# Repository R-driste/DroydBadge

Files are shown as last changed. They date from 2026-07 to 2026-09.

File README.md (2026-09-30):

# 🎫 Dristi Badge
WORK IN PROGRESS, HAS BEEN ORDERED, TROUBLESHOOTING PCB.

> A PCB hackathon badge featuring a camera, display, NFC, and thermal printer integration. Built on ESP32-S3, designed from scratch for the Outpost/Opensauce competition.

> Thank you to EasyEDA Spark for helping inspire my project, fund my PCB prototyping and supporting this endeavor. I strongly recommend it to other people looking to build new hardware.

**Key Intended Features:**
- Camera with live viewfinder
- Game mode with sprite support
- E-ink display
- NFC capability
- Thermal printer sticker output
- Rechargeable LiPo battery system
- SD card storage

---
## Board Images

<div align="center">
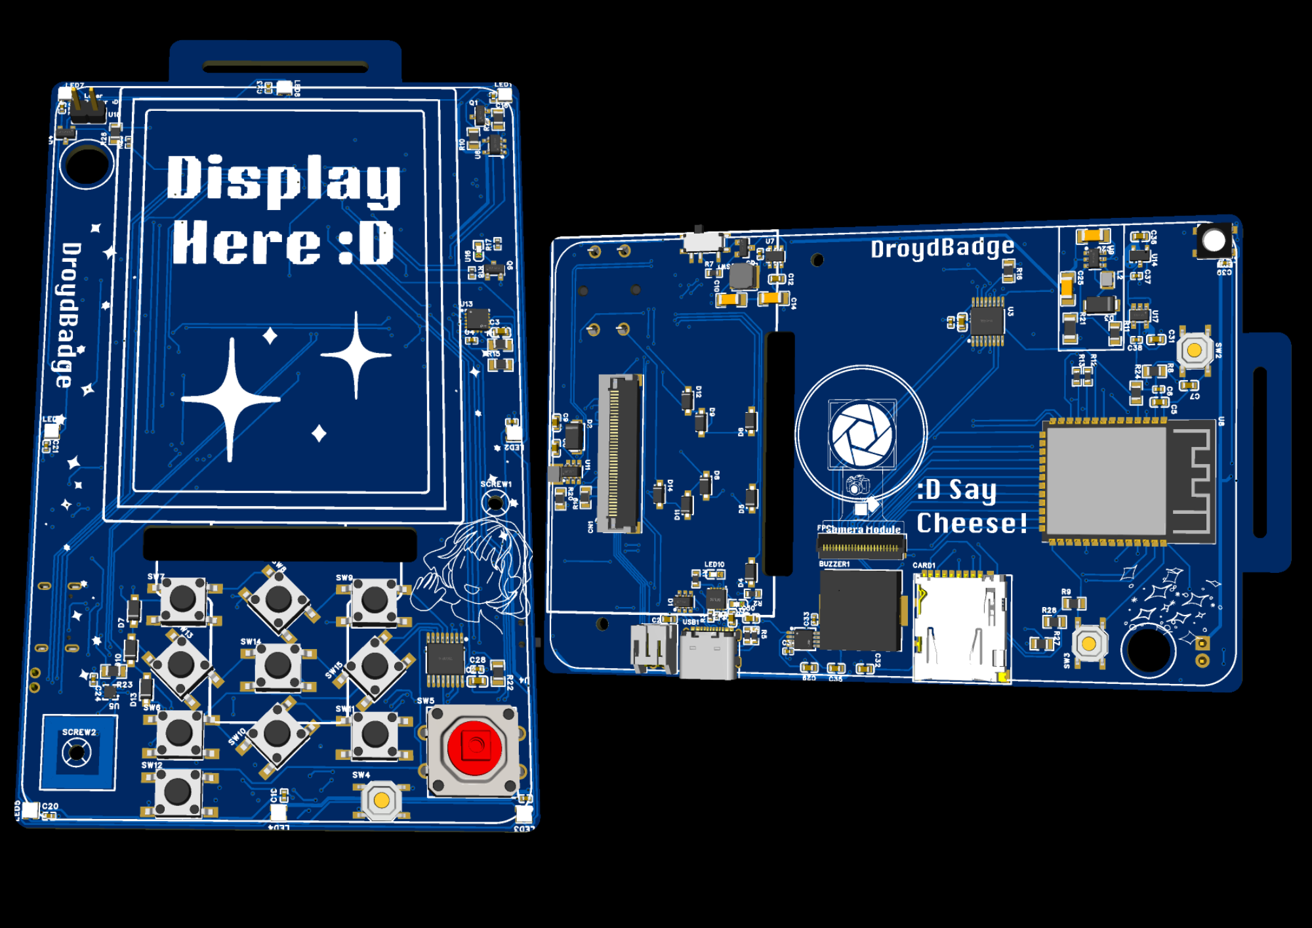
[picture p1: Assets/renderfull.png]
DroydBadge - Front View
  
</div>

<div align="center">
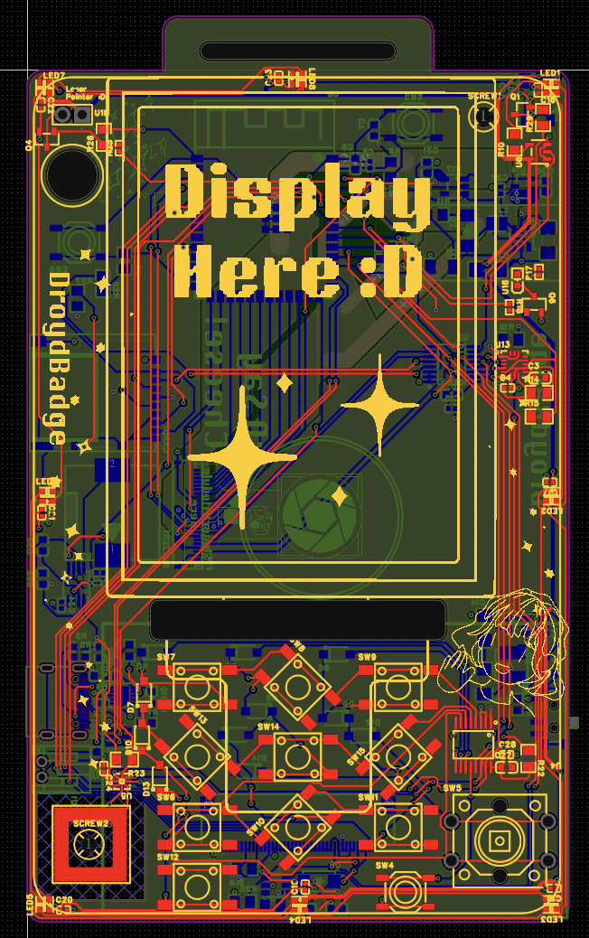
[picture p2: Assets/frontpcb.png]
PCB Layout - Top View
  
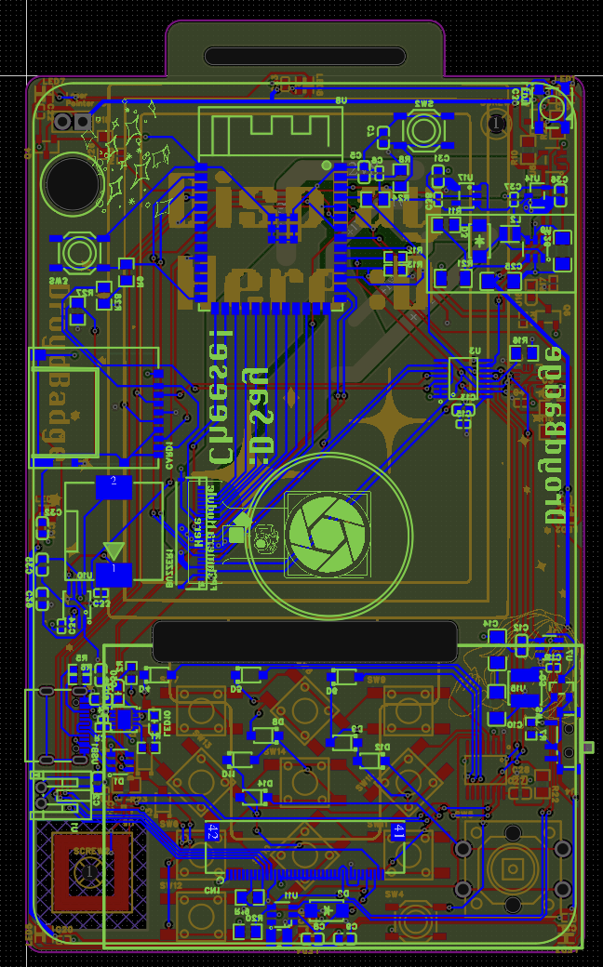
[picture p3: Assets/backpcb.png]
PCB Layout - Detailed View
  
</div>

<div align="center">
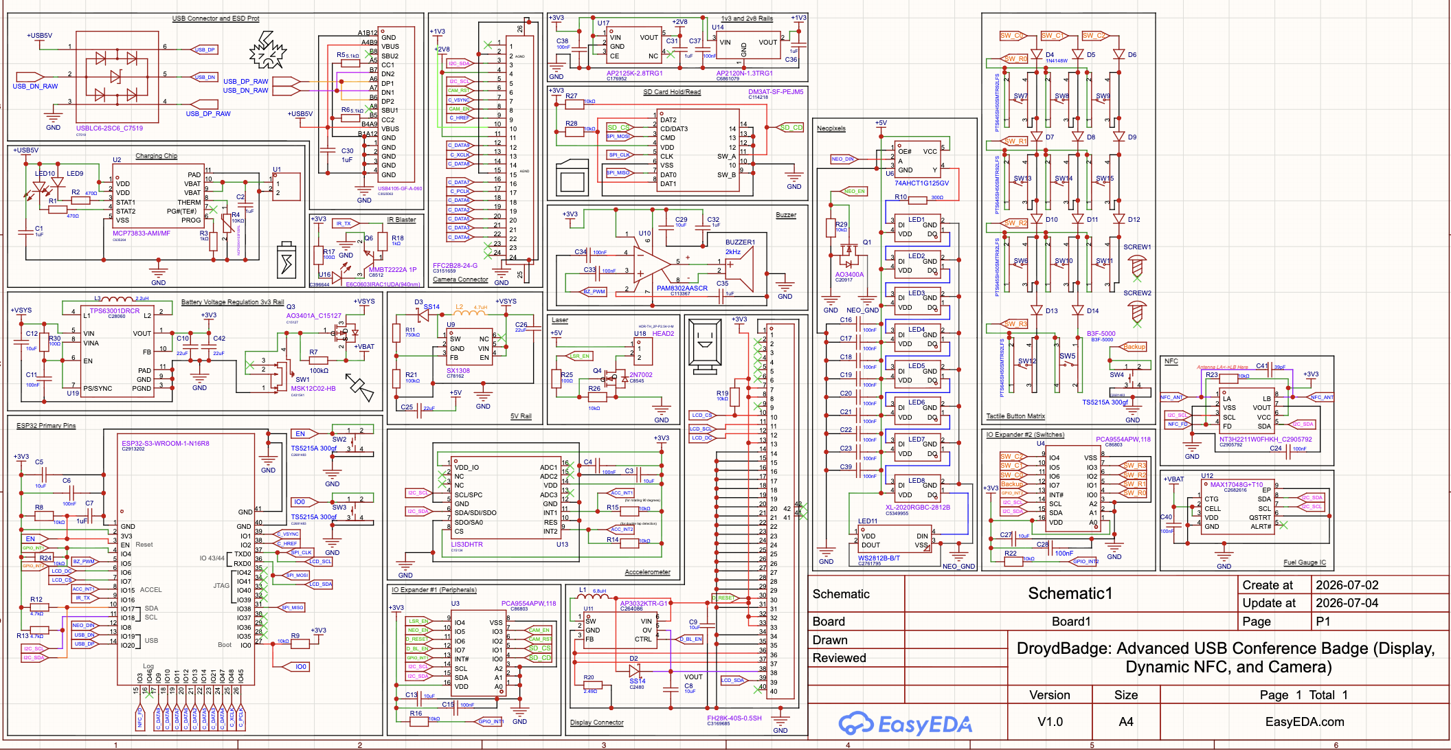
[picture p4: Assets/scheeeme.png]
Power System Schematic
  
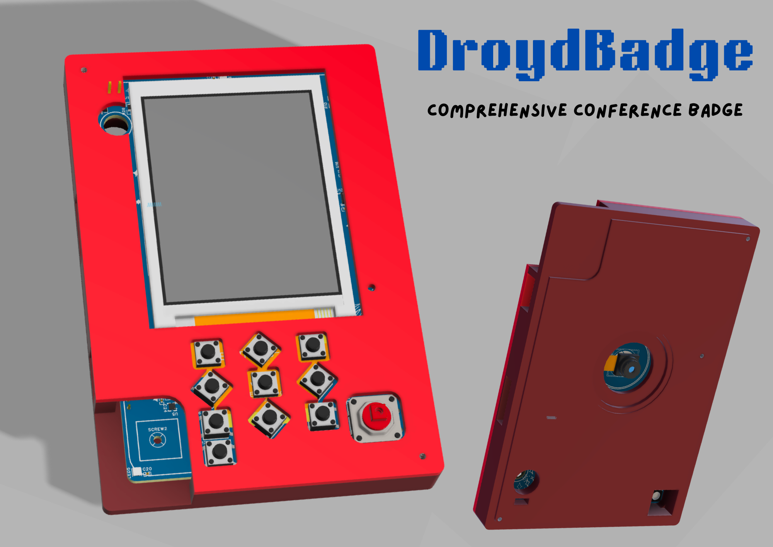
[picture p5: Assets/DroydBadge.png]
CAD
  
</div>

---

## 📁 Project Structure

- **CAD/** — 3D case design files
- **Gerber_PCB/** — PCB manufacturing files (Gerber format)
- **PCB/** — KiCad project files
- **Assets/** — Documentation and reference materials

## CAD CREDITS

Display Model
https://grabcad.com/library/serial-spi-2-8-tft-lcd-module-display-320x240-optional-touch-screen-1

Camera Model
https://grabcad.com/library/ov2640-2

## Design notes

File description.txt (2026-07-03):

3.1 ESP32 Primary Pins
U1 (ESP32-S3-WROOM-1-N16R8), the central MCU. Fans out I2C (I2C_SDA/SCL) to the accelerometer, NFC tag, and both IO expanders, SPI (SPI_MOSI/MISO/CLK) to the display and SD card, the dedicated camera DVP bus (C_DATA0-9, C_VSYNC, C_HREF, C_PCLK, C_XCLK), UART (RXD0/TXD0), and a JTAG header for debug. SW2 and SW3 (TS5215A) sit on EN and IO0 respectively, giving hardware reset and boot mode buttons.
3.2 USB Connector and ESD Protection
USB4105-GF-A-060 USB-C receptacle providing USB_DP/DN and VBUS. USBLC6-2SC6 clamps the raw D+/D- lines (USB_DP_RAW/USB_DN_RAW) before they reach the ESP32's native USB pins, protecting the exposed connector against ESD.
3.3 Battery Voltage Regulation
Q3 (AO3401A, P-channel MOSFET) load switches VBAT onto the +VSYS rail, letting the battery be gated off downstream when not needed.
3.4 Charging Chip
U2 (MCP73833-AMI/MF) linear LiPo charger. R4 is an NTC thermistor on the THERM pin for temperature qualified charging. STAT1/STAT2 drive LED9/LED10 through R3 (1k) as charge status indicators.
3.5 5V Rail
U9 (SX1308) boost converter steps VSYS up to +5V, using L2 (4.7uH), D2/D3 (SS14 Schottky) rectifiers, R10/R11/R21 feedback divider, and C25/C26 (22uF) output filtering.
3.6 3V3 Rail
U7 (AP63203WU-7) buck converter drops VSYS/5V to +3V3, using L1 (6.8uH) and C10/C14 (22uF) filtering. Powers the ESP32 and most digital peripherals.
3.7 NFC 1V3 and 2V8 Rails
Two linear LDOs isolate the NFC analog front end from the digital 3V3 rail. U14 (AP2120N-1.3) outputs +1V3, U17 (AP2125K-2.8) outputs +2V8, both sourced from +3V3. These feed the NT3H2211W0FHKH NFC IC directly, with LA/LB antenna pads broken out to a 2-pin header (HEAD2) for the loop antenna.
3.8 IO Expander #1 (Peripherals)
PCA9554APW on the I2C bus, adding 8 GPIOs for peripheral enable and reset lines that don't need to consume native ESP32 pins.
3.9 IO Expander #2 (Switches)
Second PCA9554APW reading the SW_R0-3/SW_C0-2 button matrix lines over the same I2C bus, offloading button scanning from the ESP32.
3.10 Tactile Button Matrix
9x PTS645SH50SMTR92LFS (SW7-SW15) in a 3x3 row and column grid. Diodes D6-D14 prevent ghosting on simultaneous key presses. R8/R9/R14-16/R19/R22-29 (10k) hold rows and columns at defined idle levels.
3.11 Backup Button
SW1 (MSK12C02-HB), pulled up via R7 (100k), on a dedicated Backup net, separate hardware input independent of the main matrix.
3.12 Accelerometer
U13 (LIS3DHTR) on I2C, with INT1/INT2 routed to GPIO_INT1/GPIO_INT2 for tap detection and orientation sensing. This is what detects the 90 degree rotation that triggers camera mode.
3.13 Camera Connector
FFC2B28-24-G (24-pin FPC) carries the OV2640's DVP bus (C_DATA0-9, VSYNC, HREF, PCLK, XCLK), I2C/SCCB config, CAM_EN power gate, and CAM_RST.
3.14 Display Connector
FH28K-40S-0.5SH (40-pin FPC) carries SPI (LCD_SCL/LCD_SDA), LCD_DC, LCD_CS, D_RESET, and D_BL_EN to the ILI9341V TFT. U15 (AP3032KTR-G1) is the backlight boost converter.
3.15 Neopixels
8x XL-2020RGBC-2812B (LED1-8) plus 1x WS2812B-B/T (LED11), chained on NEO_DIN and buffered through U6 (74AHCT1G125GV, 3.3V to 5V) to meet WS2812 signal timing. Q1 (AO3400A) gates power via NEO_EN.
3.16 Buzzer
Piezo (BUZZER1, 2kHz) driven differentially by U10 (PAM8302AASCR) class-D amp, fed by BZ_PWM.
3.17 IR Blaster
U16 (940nm IR LED) driven by Q6 (MMBT2222A) switched via IR_TX through R18 (1k) base resistor, with R25/R17 (100R) current limiting.
3.18 Laser
R20 (2.49R) sets current limit on the LSR_EN controlled laser driver path.
3.19 SD Card Hold/Read
DM3AT-SF-PEJM5 microSD holder providing DAT0-3, CMD, CLK, VDD/VSS, plus SD_CD (card detect) and SD_CS for SPI access.

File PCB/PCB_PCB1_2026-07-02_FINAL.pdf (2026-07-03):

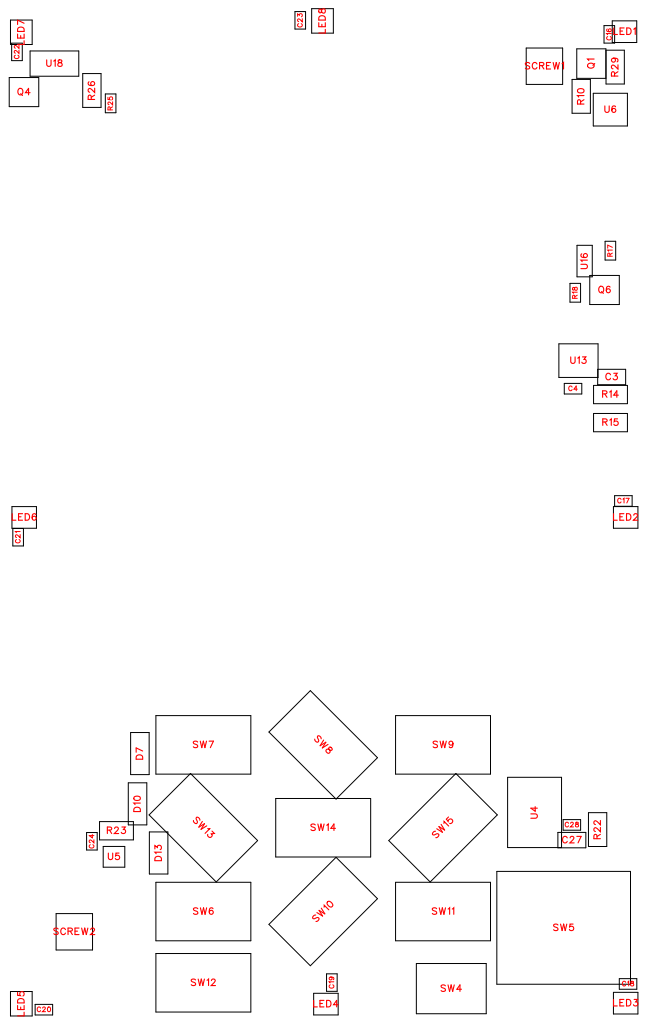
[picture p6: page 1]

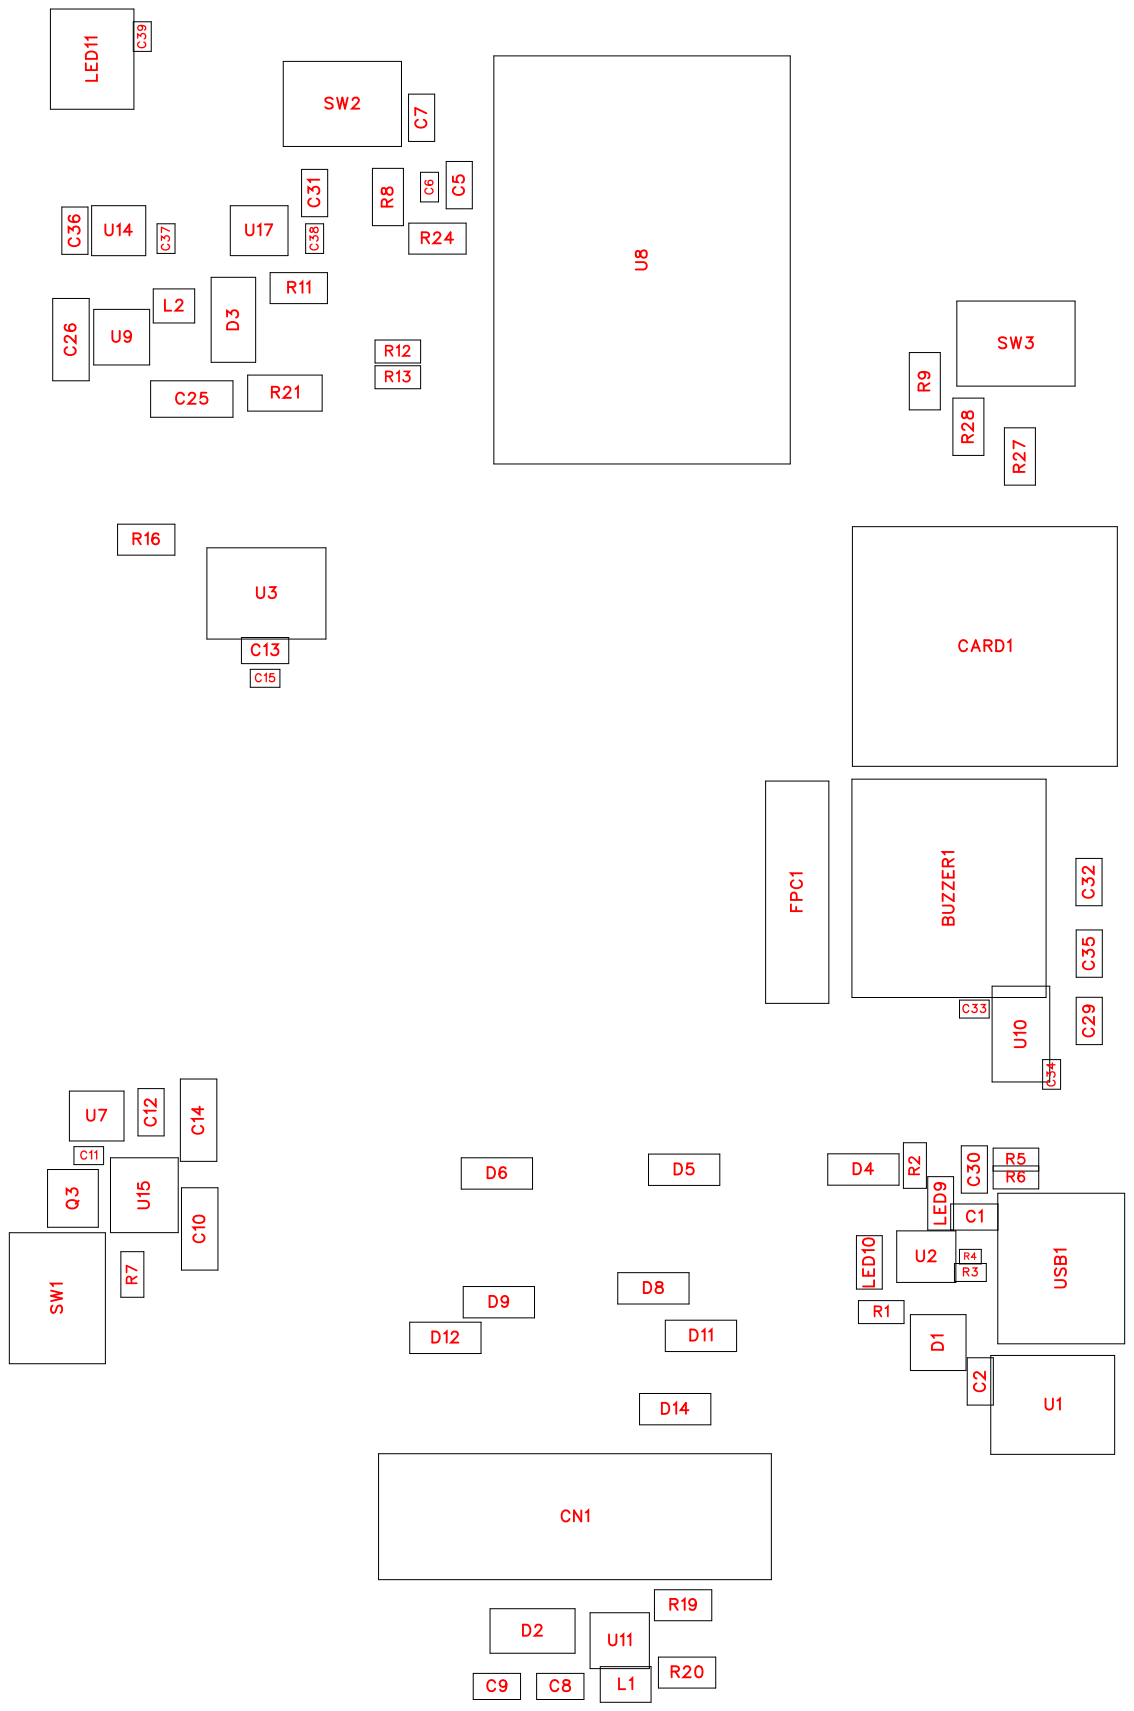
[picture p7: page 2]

No. | Quantity | Comment | Designator | Footprint | Value | Manufacturer Part | Manufacturer | Supplier Part | Supplier | JLCPCB Price | JLCPCB Stock
1 | 1 | 2kHz | BUZZER1 | BUZ-SMD_2 P-L12.0-W12 .0-L | 2kHz | PKLCS1212 E2000-R1 | muRata(村田 ) | C184513 | LCSC | 0.1658 | 1729
2 | 8 | 1uF | C1,C2,C7,C30,C31,C32,C3 5,C36 | C0603 | 1uF | CL10A105K O8NNNC | SAMSUNG( ) 三星 | C1592 | LCSC | 0.0019 | 866714
3 | 2 | 10uF | C3,C27 | C0603 | 10uF | CL10A106M Q8NNNC | SAMSUNG( ) 三星 | C1691 | LCSC | 0.0052 | 880893
4 | 11 | 100nF | C4,C16,C17,C18,C19,C20, C21,C22,C23,C24,C28 | C0402 | 100nF | CL05B104K O5NNNC | SAMSUNG( 三星 ) | C1525 | LCSC | 0.0008 | 29530801
5 | 6 | 10uF | C5,C8,C9,C12,C13,C29 | C0603 | 10uF | CL10A106M Q8NNNC | SAMSUNG( 三星 ) | C1691 | LCSC | 0.0052 | 880893
6 | 8 | 100nF | C6,C11,C15,C33,C34,C37, C38,C39 | C0402 | 100nF | CL05B104K O5NNNC | SAMSUNG( 三星 ) | C1525 | LCSC | 0.0008 | 29530801
7 | 4 | 22uF | C10,C14,C25,C26 | C1206 | 22uF | 1206X226K1 00NT | FH(风华 ) | C1859 | LCSC | 0.0313 | 8007
8 | 1 | DM3AT-SF-P EJM5 | CARD1 | SD-SMD_DM 3AT-SF-PEJ M5 | | DM3AT-SF-P EJM5 | HRS(广濑 ) | C114218 | LCSC | 0.2301 | 7384
9 | 1 | FH28K-40S-0.5SH | CN1 | FPC-SMD_4 0P-P0.50_FH 28K-40S-5S H | | FH28K-40S-0.5SH | HRS(广濑 ) | C3169685 | LCSC | 0.1356 | 7
10 | 1 | USBLC6-2S C6 | D1 | SOT-23-6_L2 .9-W1.6-P0.9 5-LS2.8-BL | | USBLC6-2S C6 | ST(意法半导 体) | C7519 | LCSC | 0.0249 | 29714
11 | 2 | SS14 | D2,D3 | SMA_L4.2-W 2.6-LS5.0-R D_1 | | SS14 | MDD(辰达半 导体 ) | C2480 | LCSC | 0.0027 | 2429994
12 | 8 | 1N4148W | D4,D5,D6,D8,D9,D11,D12, D14 | SOD-123F_L 2.7-W1.6-LS 3.8-RD | | 1N4148W | ST(先科 ) | C81598 | LCSC | 0.0018 | 3314661
13 | 3 | 1N4148W | D7,D10,D13 | SOD-123F_L 2.7-W1.6-LS 3.8-RD | | 1N4148W | ST(先科 ) | C81598 | LCSC | 0.0018 | 3314661
14 | 1 | FFC2B28-24- G | FPC1 | FPC-SMD_2 4P-P0.50_XK B_X05A10L2 4G | | FFC2B28-24- G | GCT | C3151659 | LCSC | 0.1627 | 334
15 | 1 | 6.8uH | L1 | IND-SMD_L2 .5-W2.0-1 | 6.8uH | CKCS25201 0-6.8uH/M | CENKER( 岑 科 ) | C354547 | LCSC | 0.0064 | 110
16 | 1 | 4.7uH | L2 | IND-SMD_L2 .0-W1.6 | 4.7uH | CKCS20161 0-4.7uH/M | CENKER( 岑 科 ) | C354534 | LCSC | 0.0058 | 7
17 | 8 | XL-2020RGB C-2812B | LED1,LED2,LED3,LED4,LE D5,LED6,LED7,LED8 | LED-SMD_4 P-L2.0-W2.0-BR-1 | | XL-2020RGB C-2812B | XINGLIGHT( ) 成兴光 | C5349955 | LCSC | 0.0151 | 110440
18 | 2 | KT-0603R | LED9,LED10 | LED-SMD_L 1.6-W0.8-R-RD | | KT-0603R | KENTO | C2286 | LCSC | 0.0011 | 7814332

19 | 1 | WS2812B-B/ T | LED11 | LED-SMD_4 P-L5.0-W5.0-TL_WS2812 B-B | | WS2812B-B/ T | worldsemi | C2761795 | LCSC | 0.0158 | 529034
20 | 1 | AO3400A | Q1 | SOT-23-3_L2 .9-W1.3-P1.9 0-LS2.4-BR | | AO3400A | AOS | C20917 | LCSC | 0.0125 | 1280541
21 | 1 | AO3401A | Q3 | SOT-23_L2.9 -W1.3-P1.90-LS2.4-BR | | AO3401A | AOS | C15127 | LCSC | 0.0148 | 540030
22 | 1 | 2N7002 | Q4 | SOT-23-3_L2 .9-W1.3-P1.9 0-LS2.4-BR | | 2N7002 | CJ(江苏长电 / 长晶 ) | C8545 | LCSC | 0.0024 | 385928
23 | 1 | MMBT2222A 1P | Q6 | SOT-23-3_L2 .9-W1.3-P1.9 0-LS2.4-BR | | MMBT2222A 1P | CJ(江苏长电 / ) 长晶 | C8512 | LCSC | 0.0026 | 207505
24 | 2 | 470 | R1,R2 | R0603 | 470 | RCT03470R FLF | HKR(香港电 阻) | C177666 | LCSC | 0.0003 | 2142
25 | 1 | 1k | R3 | R0402 | 1k | 0402WGF10 01TCE | UNI-ROYAL( ) 厚声 | C11702 | LCSC | 0.0008 | 1599390
26 | 1 | NCP03XH10 3F05RL | R4 | R0201 | 10K | NCP03XH10 3F05RL | muRata(村田 ) | C98098 | LCSC | 0.0036 | 108316
27 | 2 | 5.1k | R5,R6 | R0603 | 5.1k | RCT035K1F LF | HKR(香港电 阻) | C177641 | LCSC | 0.0003 | 12
28 | 1 | 100k | R7 | R0603 | 100k | RCT03100K FLF | HKR(香港电 阻) | C177608 | LCSC | 0.0003 | 152
29 | 7 | 10k | R8,R9,R16,R19,R24,R27,R 28 | R0805 | 10k | RCT0510KF LF | HKR(香港电 阻) | C702829 | LCSC | 0.0006 | 6385
30 | 1 | 300 | R10 | R0805 | 300 | 0805W8F300 0T5E | UNI-ROYAL( ) 厚声 | C17617 | LCSC | 0.0006 | 462359
31 | 1 | 750k | R11 | R0805 | 750k | 0805W8F750 3T5E | UNI-ROYAL( 厚声 ) | C17817 | LCSC | 0.0007 | 34234
32 | 2 | 4.7k | R12,R13 | R0603 | 4.7k | RCT034K7F LF | HKR(香港电 阻) | C177609 | LCSC | 0.0002 | 712
33 | 6 | 10k | R14,R15,R22,R23,R26,R29 | R0805 | 10k | RCT0510KF LF | HKR(香港电 阻) | C702829 | LCSC | 0.0006 | 6385
34 | 2 | 100 | R17,R25 | R0402 | 100 | RCT02100R FLF | HKR(香港电 阻) | C173685 | LCSC | 0.0002 | 13171
35 | 1 | 1k | R18 | R0402 | 1k | RCT021KFL F | HKR(香港电 阻) | C173697 | LCSC | 0.0002 | 4472
36 | 1 | 2.49 | R20 | R0805 | 2.49 | 0805W8F249 KT5E | UNI-ROYAL( 厚声 ) | C17525 | LCSC | 0.0005 | 1246
37 | 1 | 100k | R21 | R1206 | 100k | 1206W4F100 3T5E | UNI-ROYAL( 厚声 ) | C17900 | LCSC | 0.0012 | 443325
38 | 2 | Screw-Hole-M2 | SCREW1,SCREW2 | Screw-Hole-M2
39 | 1 | MSK12C02-HB | SW1 | SW-TH_MSK 12C02-HB-1 | | MSK12C02-HB | SHOU HAN(首韩 ) | C431541 | LCSC | 0.009 | 48525

40 | 2 | TS5215A 300gf | SW2,SW3 | SW-SMD_4P -L5.2-W5.2-P 3.70-LS6.4 | | TS5215A 300gf | SHOU HAN(首韩 ) | C2681483 | LCSC | 0.0033 | 50061
41 | 1 | TS5215A 300gf | SW4 | SW-SMD_4P -L5.2-W5.2-P 3.70-LS6.4 | | TS5215A 300gf | SHOU HAN(首韩 ) | C2681483 | LCSC | 0.0033 | 50061
42 | 1 | B3F-5000 | SW5 | KEY-TH_4P-L12.0-W12.0-P5.0-LS12.5-EH | | B3F-5000 | OMRON( 欧 ) 姆龙 | C93156 | LCSC | 0.0263 | 8420
43 | 10 | PTS645SH5 0SMTR92LF S | SW6,SW7,SW8,SW9,SW10 ,SW11,SW12,SW13,SW14, SW15 | KEY-SMD_4 P-L6.0-W6.0-P4.50-LS9.0 | | PTS645SH5 0SMTR92LF S | C&K | C221869 | LCSC | 0.0634 | 4576
44 | 1 | S2B-PH-K-S-GW | U1 | CONN-TH_S 2B-PH-K-S-G W | | S2B-PH-K-S-GW | JST | C157932 | LCSC | 0.026 | 20496
45 | 1 | MCP73833-A MI/MF | U2 | DFN-10_L3.0 -W3.0-P0.50-BL-EP-1 | | MCP73833-A MI/MF | MICROCHIP( ) 美国微芯 | C635264 | LCSC | 0.2759 | 588
46 | 1 | PCA9554AP W,118 | U3 | TSSOP-16_L 5.0-W4.4-P0. 65-LS6.4-BL | | PCA9554AP W,118 | NXP(恩智浦 ) | C86803 | LCSC | 0.2709 | 2706
47 | 1 | PCA9554AP W,118 | U4 | TSSOP-16_L 5.0-W4.4-P0. 65-LS6.4-BL | | PCA9554AP W,118 | NXP(恩智浦 ) | C86803 | LCSC | 0.2709 | 2706
48 | 1 | 13.56MHz | U5 | XQFN-8_L1. 6-W1.6-P0.5 0-TL | 13.56MHz | NT3H2211W 0FHKH | NXP(恩智浦 ) | C2905792 | LCSC | 0.1339 | 2
49 | 1 | 74AHCT1G1 25GV | U6 | SOT-23-5_L3 .0-W1.7-P0.9 5-LS2.8-BL | | 74AHCT1G1 25GV | MDD(辰达半 导体 ) | C52140417 | LCSC | 0.0118 | 2850
50 | 1 | AP63203WU -7 | U7 | TSOT-26_L2. 9-W1.6-P0.9 5-LS2.8-BL | | AP63203WU -7 | DIODES( 美 台 ) | C780769 | LCSC | 0.0881 | 9791
51 | 1 | 2.4GHz | U8 | WIRELM-SM D_ESP32-S3 -WROOM-1 | 2.4GHz | ESP32-S3-W ROOM-1-N1 6R8 | ESPRESSIF( 乐鑫 ) | C2913202 | LCSC | 0.7988 | 50419
52 | 1 | SX1308 | U9 | SOT-23-6_L2 .9-W1.6-P0.9 5-LS2.8-BL | | SX1308 | SX(硕芯科技 ) | C78162 | LCSC | 0.0159 | 18503
53 | 1 | PAM8302AA SCR | U10 | MSOP-8_L3. 0-W3.0-P0.6 5-LS5.0-BL | | PAM8302AA SCR | DIODES( 美 台 ) | C113367 | LCSC | 0.032 | 6851
54 | 1 | AP3032KTR-G1 | U11 | SOT-23-6_L2 .9-W1.6-P0.9 5-LS2.8-BR | - AP3032KTR- | G1 | DIODES( 美 台 ) | C264086 | LCSC | 0.0369 | 5935
55 | 1 | LIS3DHTR | U13 | LGA-16_L3.0 -W3.0-P0.50-TL | | LIS3DHTR | ST(意法半导 体) | C15134 | LCSC | 0.2327 | 6407
56 | 1 | AP2120N-1.3 TRG1 | U14 | SOT-23-3_L2 .9-W1.5-P2.0 -LS2.5-BR | | AP2120N-1.3 TRG1 | DIODES( 美 ) 台 | C6861079 | LCSC | 0.0186 | 470

57 | 1 | 3.9uH | U15 | IND-SMD_L4 .0-W4.0 | 3.9uH | SWPA4030S 3R9MT | Sunlord(顺络 ) | C96899 | LCSC | 0.0133 | 1645
58 | 1 | E6C0603IRA C1UDA(940n m) | U16 | LED-SMD_L 1.6-W0.8-R-RD | | E6C0603IRA C1UDA(940n m) | ekinglux(亿晶 源) | C396644 | LCSC | 0.0076 | 2993
59 | 1 | AP2125K-2.8 TRG1 | U17 | SOT-23-5_L3 .0-W1.7-P0.9 5-LS2.8-BR | | AP2125K-2.8 TRG1 | DIODES( 美 ) 台 | C176952 | LCSC | 0.011 | 1367
60 | 1 | HEAD2 | U18 | HDR-TH_2P-P2.54-V-M | | HEAD2 | | C990001003 0 | LCSC | 0.0002 | 0
61 | 1 | USB4105-GF -A-060 | USB1 | USB-C-SMD _GT-USB-70 10E-1 | | USB4105-GF -A-060 | GCT | C3025063 | LCSC | 0.1588 | 1061

Layer | Mounting Style
B | SMT
B | SMT
T | SMT
T | SMT
B | SMT
B | SMT
B | SMT
B | SMT
B | SMT
B | SMT
B | SMT
B | SMT
T | SMT
B | SMT
B | SMT
B | SMT
T | SMT
B | SMT
B | SMT
T | SMT
B | SMT
T | SMT
T | SMT
B | SMT
B | SMT
B | SMT
B | SMT
B | SMT
B | SMT
T | SMT
B | SMT
B | SMT
T | SMT
T | SMT
T | SMT
B | SMT
B | SMT
T | DIP
B | SMT

B | SMT T | SMT T | DIP T | SMT B | DIP B | SMT B | SMT T | SMT T | SMT T | SMT B | SMT B | SMT B | SMT B | SMT B | SMT T | SMT B | SMT B | SMT T | SMT B | SMT T | DIP B | DIP

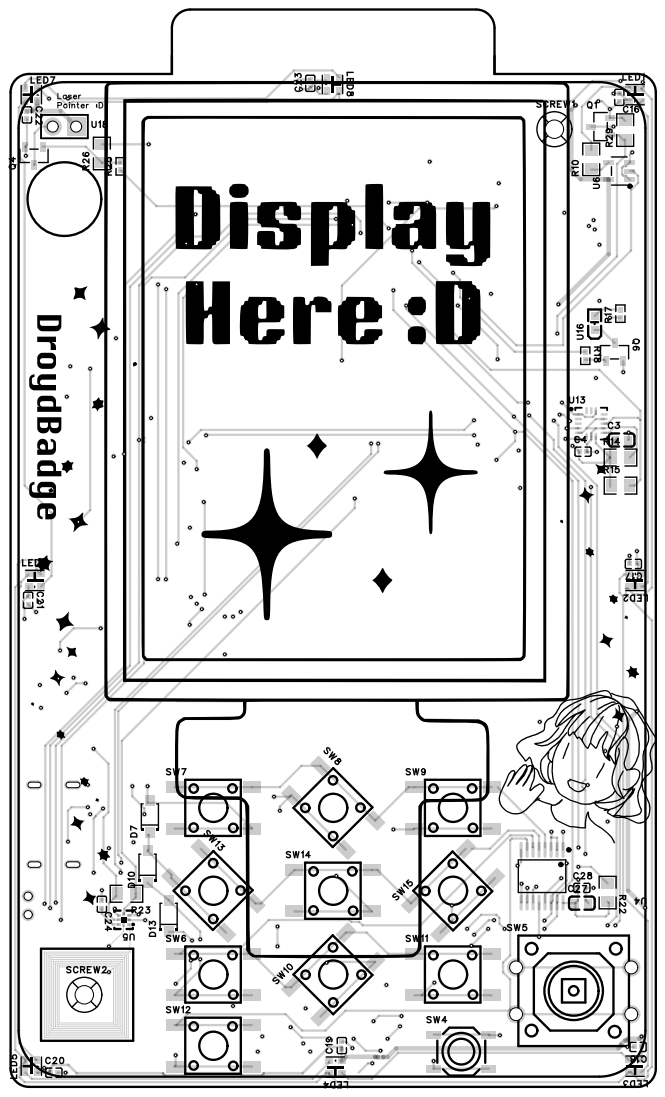
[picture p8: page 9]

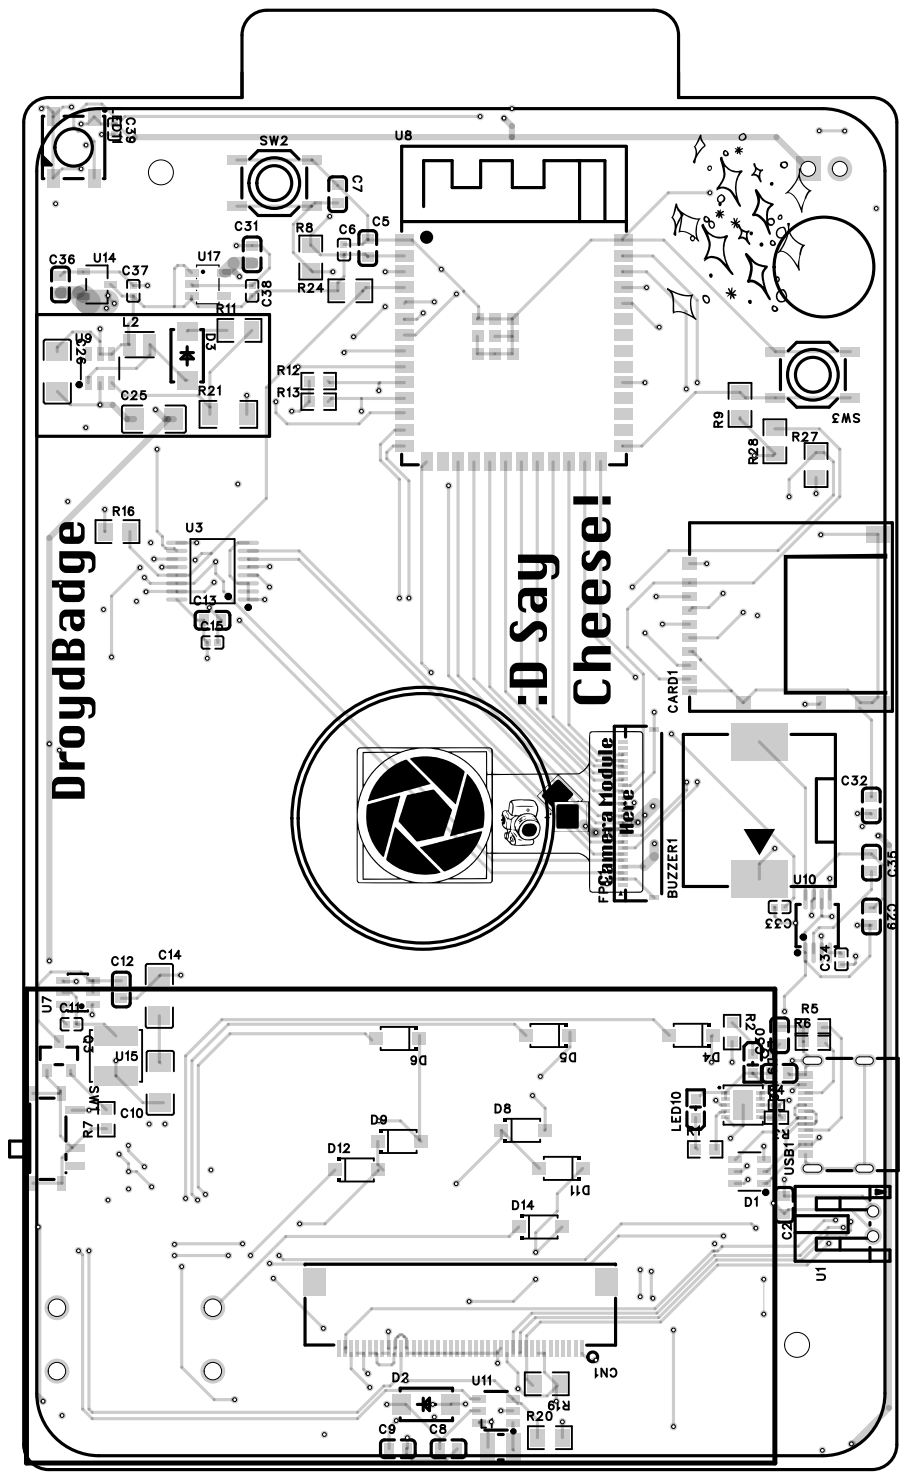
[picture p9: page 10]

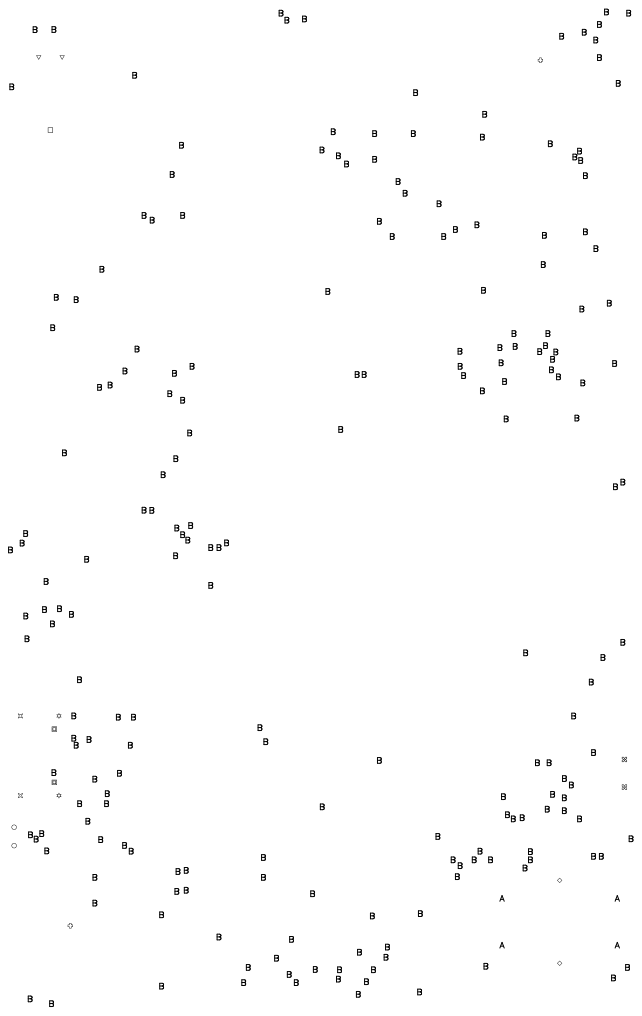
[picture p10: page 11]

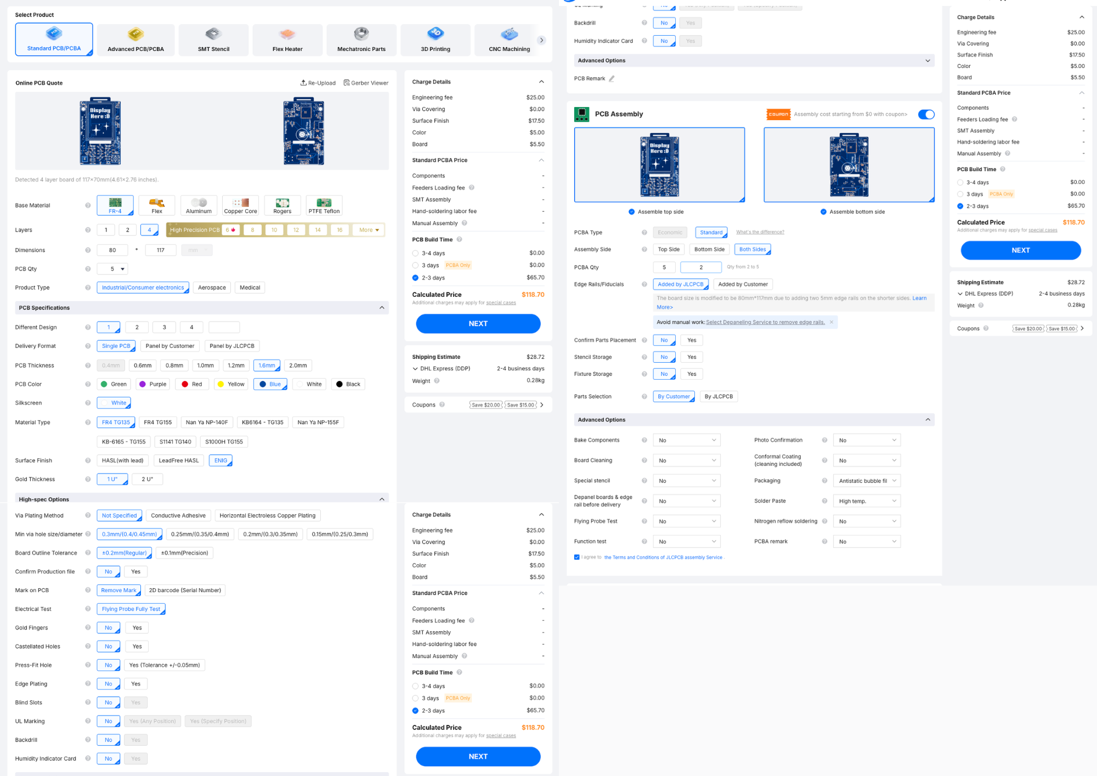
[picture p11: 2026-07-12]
Assets/schematic.png

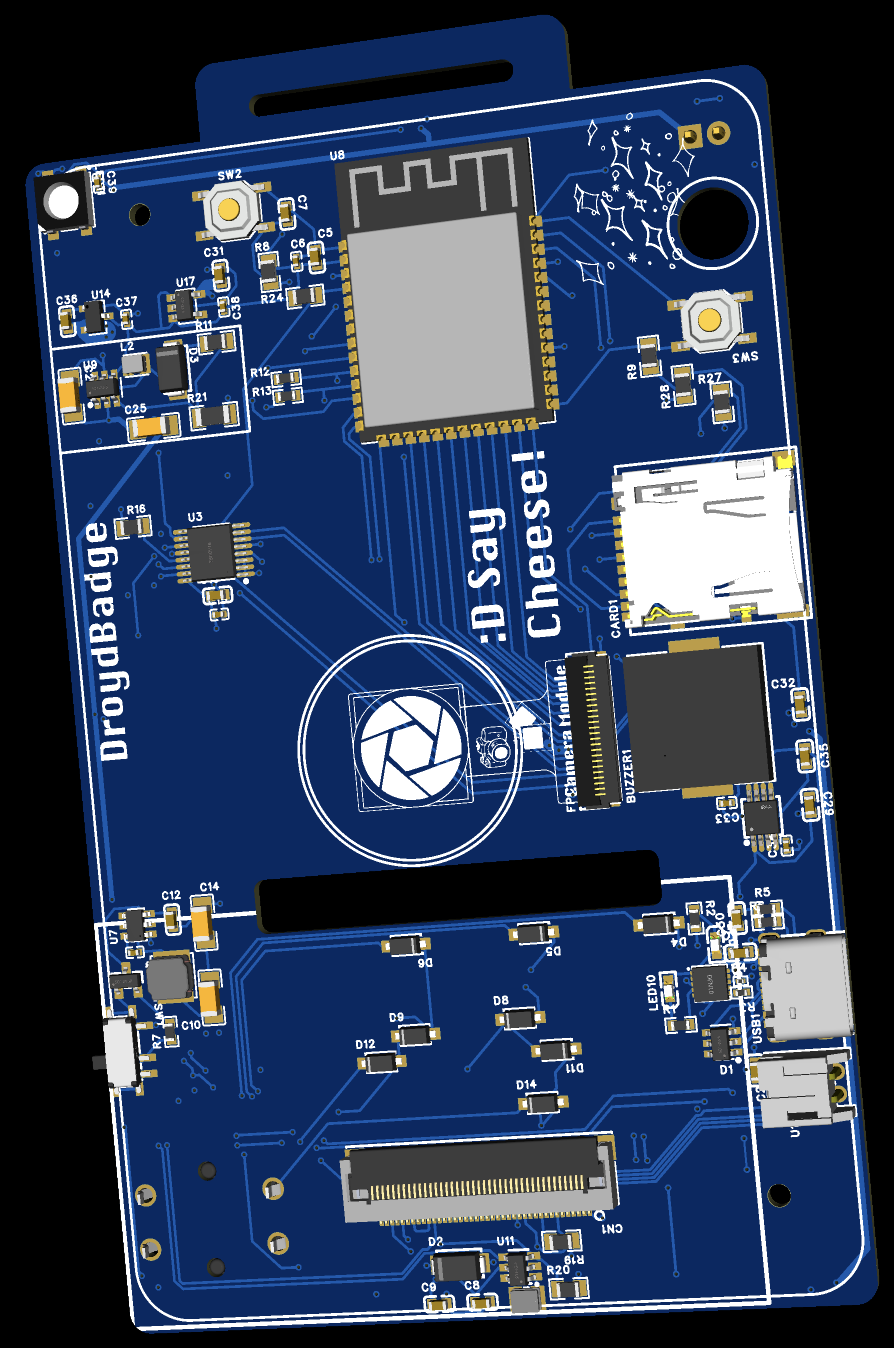
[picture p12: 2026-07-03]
Assets/backrender.png

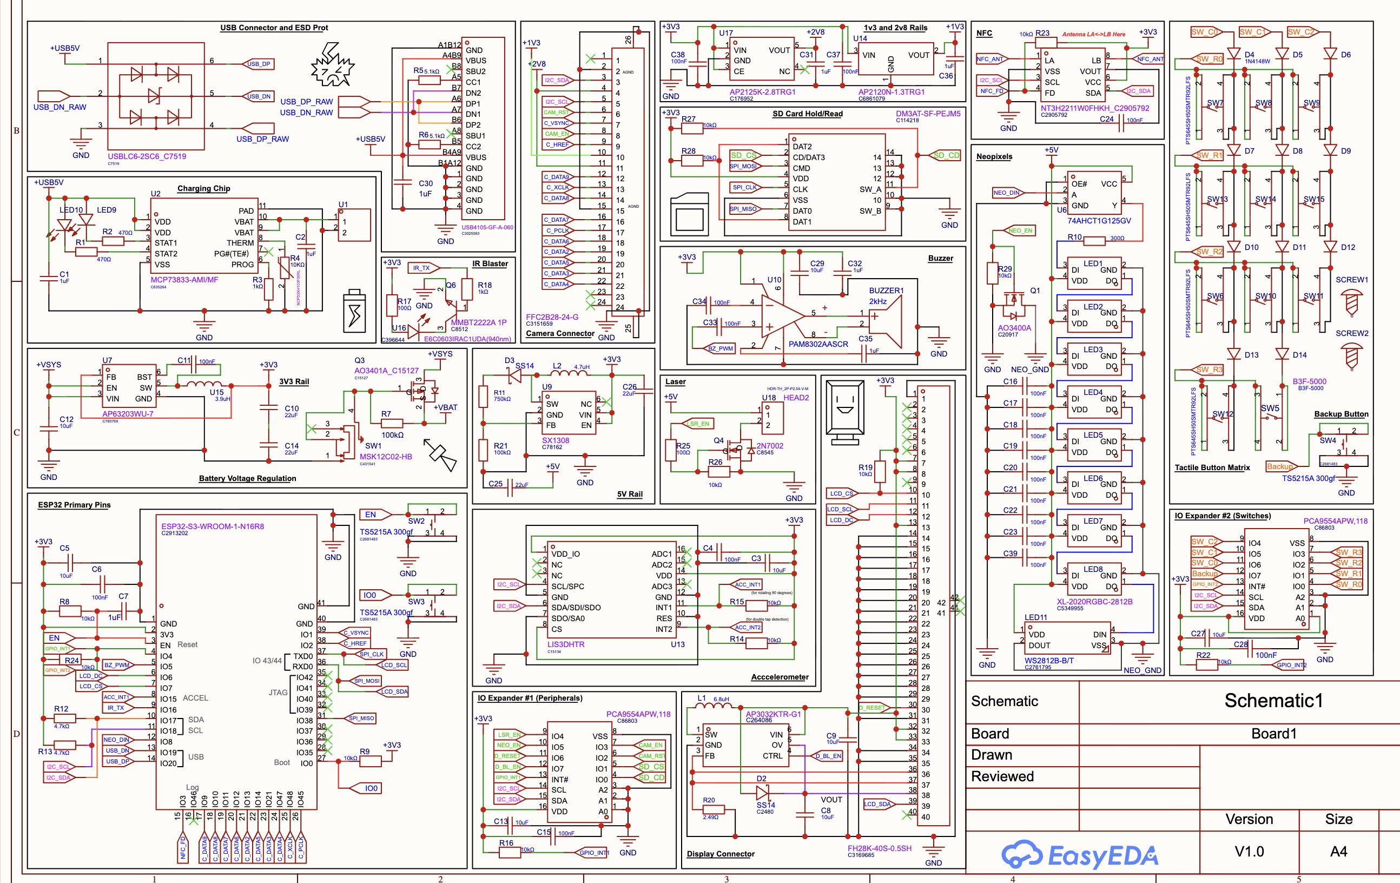
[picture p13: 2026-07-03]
Assets/schema.png

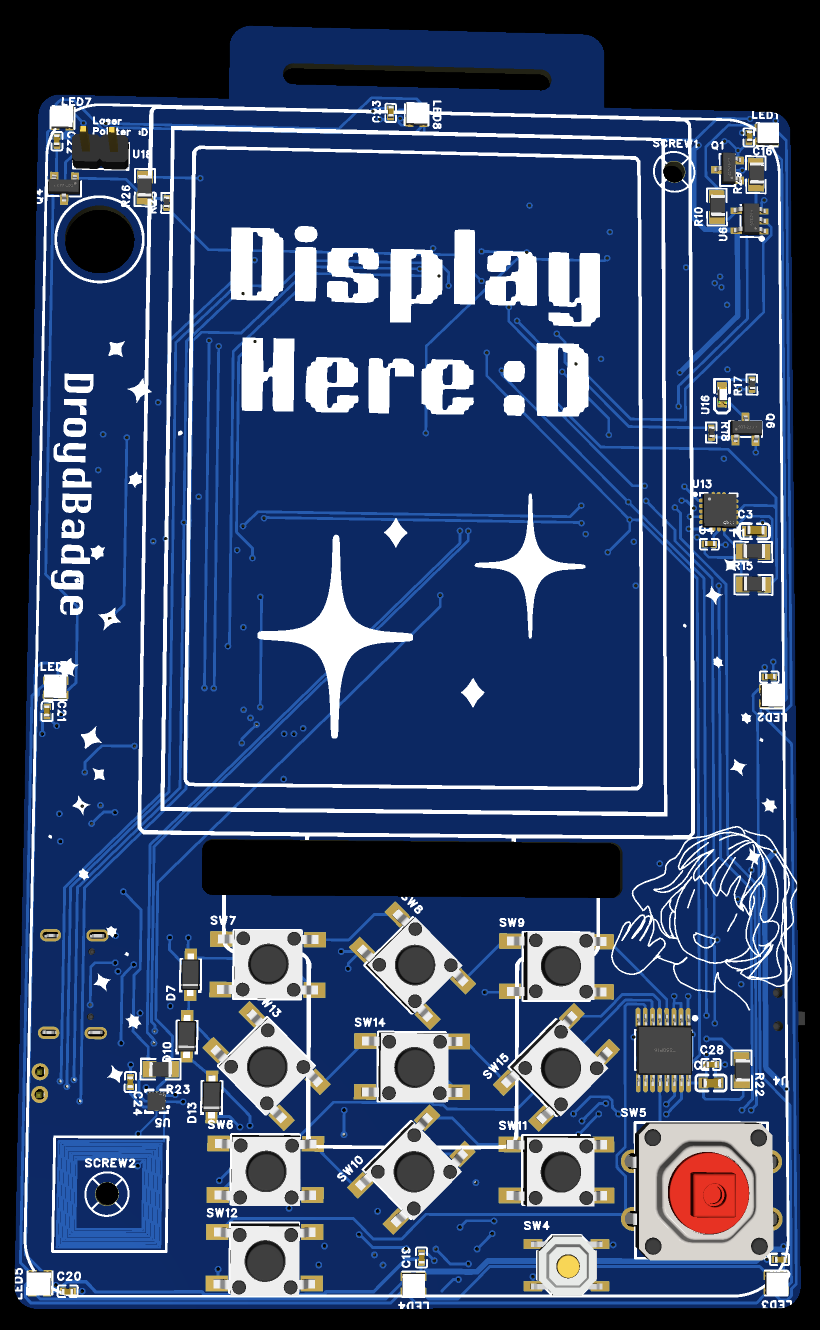
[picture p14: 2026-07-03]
Assets/frontrender.png

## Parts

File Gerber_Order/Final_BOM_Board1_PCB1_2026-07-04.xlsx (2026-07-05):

No. | Quantity | Comment | Designator | Footprint | Value | Manufacturer Part | Manufacturer | Supplier Part | Supplier | JLCPCB Price | JLCPCB Stock | Layer | Mounting Style
1 | 1 | 2kHz | BUZZER1 | BUZ-SMD_2P-L12.0-W12.0-L | 2kHz | PKLCS1212E2000-R1 | muRata(村田) | C184513 | LCSC | 0.1661 | 718 | B | SMT
2 | 8 | 1uF | C1,C2,C7,C30,C31,C32,C35,C36 | C0603 | 1uF | CL10A105KO8NNNC | SAMSUNG(三星) | C1592 | LCSC | 0.0023 | 1243452 | B | SMT
3 | 2 | 10uF | C3,C27 | C0603 | 10uF | CL10A106MQ8NNNC | SAMSUNG(三星) | C1691 | LCSC | 0.0052 | 856479 | T | SMT
4 | 11 | 100nF | C4,C16,C17,C18,C19,C20,C21,C22,C23,C24,C28 | C0402 | 100nF | CL05B104KO5NNNC | SAMSUNG(三星) | C1525 | LCSC | 0.0014 | 28964194 | T | SMT
5 | 6 | 10uF | C5,C8,C9,C12,C13,C29 | C0603 | 10uF | CL10A106MQ8NNNC | SAMSUNG(三星) | C1691 | LCSC | 0.0052 | 856479 | B | SMT
6 | 9 | 100nF | C6,C11,C15,C33,C34,C37,C38,C39,C40 | C0402 | 100nF | CL05B104KO5NNNC | SAMSUNG(三星) | C1525 | LCSC | 0.0014 | 28964194 | B | SMT
7 | 4 | 22uF | C10,C25,C26,C42 | C1206 | 22uF | 1206X226K100NT | FH(风华) | C1859 | LCSC | 0.0314 | 7781 | B | SMT
8 | 1 | 39pF | C41 | C0402 | 39pF | 0402CG390J500NT | FH(风华) | C1563 | LCSC | 0.0012 | 145068 | T | SMT
9 | 1 | DM3AT-SF-PEJM5 | CARD1 | SD-SMD_DM3AT-SF-PEJM5 |  | DM3AT-SF-PEJM5 | HRS(广濑) | C114218 | LCSC | 0.2305 | 8237 | B | SMT
10 | 1 | FH28K-40S-0.5SH | CN1 | FPC-SMD_40P-P0.50_FH28K-40S-5SH |  | FH28K-40S-0.5SH | HRS(广濑) | C3169685 | LCSC | 0.1358 | 7 | B | SMT
11 | 1 | USBLC6-2SC6 | D1 | SOT-23-6_L2.9-W1.6-P0.95-LS2.8-BL |  | USBLC6-2SC6 | ST(意法半导体) | C7519 | LCSC | 0.027 | 18783 | B | SMT
12 | 2 | SS14 | D2,D3 | SMA_L4.2-W2.6-LS5.0-RD_1 |  | SS14 | MDD(辰达半导体) | C2480 | LCSC | 0.0027 | 2401750 | B | SMT
13 | 8 | 1N4148W | D4,D5,D6,D8,D9,D11,D12,D14 | SOD-123F_L2.7-W1.6-LS3.8-RD |  | 1N4148W | ST(先科) | C81598 | LCSC | 0.0018 | 3180125 | B | SMT
14 | 3 | 1N4148W | D7,D10,D13 | SOD-123F_L2.7-W1.6-LS3.8-RD |  | 1N4148W | ST(先科) | C81598 | LCSC | 0.0018 | 3180125 | T | SMT
15 | 1 | FFC2B28-24-G | FPC1 | FPC-SMD_24P-P0.50_XKB_X05A10L24G |  | FFC2B28-24-G | GCT | C3151659 | LCSC | 0.163 | 334 | B | SMT
16 | 1 | 6.8uH | L1 | IND-SMD_L2.5-W2.0-1 | 6.8uH | CKCS252010-6.8uH/M | CENKER(岑科) | C354547 | LCSC | 0.0064 | 110 | B | SMT
17 | 1 | 4.7uH | L2 | IND-SMD_L2.0-W1.6 | 4.7uH | CKCS201610-4.7uH/M | CENKER(岑科) | C354534 | LCSC | 0.0058 | 7 | B | SMT
18 | 1 | 2.2uH | L3 | IND-SMD_L4.0-W4.0_LQH44PN2R2MP0L | 2.2uH | SMNR4020-2.2UH | SXN(顺翔诺) | C135262 | LCSC | 0.0087 | 69329 | B | SMT
19 | 8 | XL-2020RGBC-2812B | LED1,LED2,LED3,LED4,LED5,LED6,LED7,LED8 | LED-SMD_4P-L2.0-W2.0-BR-1 |  | XL-2020RGBC-2812B | XINGLIGHT(成兴光) | C5349955 | LCSC | 0.0152 | 108419 | T | SMT
20 | 2 | KT-0603R | LED9,LED10 | LED-SMD_L1.6-W0.8-R-RD |  | KT-0603R | KENTO | C2286 | LCSC | 0.0011 | 7663588 | B | SMT
21 | 1 | WS2812B-B/T | LED11 | LED-SMD_4P-L5.0-W5.0-TL_WS2812B-B |  | WS2812B-B/T | worldsemi | C2761795 | LCSC | 0.0158 | 526104 | B | SMT
22 | 1 | AO3400A | Q1 | SOT-23-3_L2.9-W1.3-P1.90-LS2.4-BR |  | AO3400A | AOS | C20917 | LCSC | 0.0126 | 1208838 | T | SMT
23 | 1 | AO3401A | Q3 | SOT-23_L2.9-W1.3-P1.90-LS2.4-BR |  | AO3401A | AOS | C15127 | LCSC | 0.0148 | 511309 | B | SMT
24 | 1 | 2N7002 | Q4 | SOT-23-3_L2.9-W1.3-P1.90-LS2.4-BR |  | 2N7002 | CJ(江苏长电/长晶) | C8545 | LCSC | 0.0027 | 373561 | T | SMT
25 | 1 | MMBT2222A 1P | Q6 | SOT-23-3_L2.9-W1.3-P1.90-LS2.4-BR |  | MMBT2222A 1P | CJ(江苏长电/长晶) | C8512 | LCSC | 0.0028 | 198794 | T | SMT
26 | 2 | 470Ω | R1,R2 | R0603 | 470Ω | RCT03470RFLF | HKR(香港电阻) | C177666 | LCSC | 0.0003 | 2222 | B | SMT
27 | 1 | 1kΩ | R3 | R0402 | 1kΩ | 0402WGF1001TCE | UNI-ROYAL(厚声) | C11702 | LCSC | 0.0008 | 1231792 | B | SMT
28 | 1 | NCP03XH103F05RL | R4 | R0201 | 10KΩ | NCP03XH103F05RL | muRata(村田) | C98098 | LCSC | 0.0036 | 115691 | B | SMT
29 | 2 | 5.1kΩ | R5,R6 | R0603 | 5.1kΩ | RCT035K1FLF | HKR(香港电阻) | C177641 | LCSC | 0.0003 | 12 | B | SMT
30 | 1 | 100kΩ | R7 | R0603 | 100kΩ | RCT03100KFLF | HKR(香港电阻) | C177608 | LCSC | 0.0003 | 152 | B | SMT
31 | 7 | 10kΩ | R8,R9,R16,R19,R24,R27,R28 | R0805 | 10kΩ | RCT0510KFLF | HKR(香港电阻) | C702829 | LCSC | 0.0006 | 6285 | B | SMT
32 | 1 | 300Ω | R10 | R0805 | 300Ω | 0805W8F3000T5E | UNI-ROYAL(厚声) | C17617 | LCSC | 0.0006 | 456160 | T | SMT
33 | 1 | 750kΩ | R11 | R0805 | 750kΩ | 0805W8F7503T5E | UNI-ROYAL(厚声) | C17817 | LCSC | 0.0007 | 34174 | B | SMT
34 | 2 | 4.7kΩ | R12,R13 | R0603 | 4.7kΩ | RCT034K7FLF | HKR(香港电阻) | C177609 | LCSC | 0.0003 | 23 | B | SMT
35 | 6 | 10kΩ | R14,R15,R22,R23,R26,R29 | R0805 | 10kΩ | RCT0510KFLF | HKR(香港电阻) | C702829 | LCSC | 0.0006 | 6285 | T | SMT
36 | 2 | 100Ω | R17,R25 | R0402 | 100Ω | RCT02100RFLF | HKR(香港电阻) | C173685 | LCSC | 0.0002 | 12471 | T | SMT
37 | 1 | 1kΩ | R18 | R0402 | 1kΩ | RCT021KFLF | HKR(香港电阻) | C173697 | LCSC | 0.0002 | 3272 | T | SMT
38 | 1 | 2.49Ω | R20 | R0805 | 2.49Ω | 0805W8F249KT5E | UNI-ROYAL(厚声) | C17525 | LCSC | 0.0005 | 1146 | B | SMT
39 | 1 | 100kΩ | R21 | R1206 | 100kΩ | 1206W4F1003T5E | UNI-ROYAL(厚声) | C17900 | LCSC | 0.0037 | 514049 | B | SMT
40 | 1 | 100Ω | R30 | R0402 | 100Ω | RCT02100RFLF | HKR(香港电阻) | C173685 | LCSC | 0.0002 | 12471 | B | SMT
41 | 2 | Screw-Hole-M2 | SCREW1,SCREW2 | Screw-Hole-M2 |  |  |  |  |  |  |  | T | DIP
42 | 1 | MSK12C02-HB | SW1 | SW-TH_MSK12C02-HB-1 |  | MSK12C02-HB | SHOU HAN(首韩) | C431541 | LCSC | 0.0091 | 48101 | B | SMT
43 | 2 | TS5215A 300gf | SW2,SW3 | SW-SMD_4P-L5.2-W5.2-P3.70-LS6.4 |  | TS5215A 300gf | SHOU HAN(首韩) | C2681483 | LCSC | 0.0033 | 50051 | B | SMT
44 | 1 | TS5215A 300gf | SW4 | SW-SMD_4P-L5.2-W5.2-P3.70-LS6.4 |  | TS5215A 300gf | SHOU HAN(首韩) | C2681483 | LCSC | 0.0033 | 50051 | T | SMT
45 | 1 | B3F-5000 | SW5 | KEY-TH_4P-L12.0-W12.0-P5.0-LS12.5-EH |  | B3F-5000 | OMRON(欧姆龙) | C93156 | LCSC | 0.0263 | 8380 | T | DIP
46 | 10 | PTS645SH50SMTR92LFS | SW6,SW7,SW8,SW9,SW10,SW11,SW12,SW13,SW14,SW15 | KEY-SMD_4P-L6.0-W6.0-P4.50-LS9.0 |  | PTS645SH50SMTR92LFS | C&K | C221869 | LCSC | 0.0635 | 4531 | T | SMT
47 | 1 | S2B-PH-K-S-GW | U1 | CONN-TH_S2B-PH-K-S-GW |  | S2B-PH-K-S-GW | JST | C157932 | LCSC | 0.026 | 20511 | B | DIP
48 | 1 | MCP73833-AMI/MF | U2 | DFN-10_L3.0-W3.0-P0.50-BL-EP-1 |  | MCP73833-AMI/MF | MICROCHIP(美国微芯) | C635264 | LCSC | 0.2764 | 573 | B | SMT
49 | 1 | PCA9554APW,118 | U3 | TSSOP-16_L5.0-W4.4-P0.65-LS6.4-BL |  | PCA9554APW,118 | NXP(恩智浦) | C86803 | LCSC | 0.2713 | 2705 | B | SMT
50 | 1 | PCA9554APW,118 | U4 | TSSOP-16_L5.0-W4.4-P0.65-LS6.4-BL |  | PCA9554APW,118 | NXP(恩智浦) | C86803 | LCSC | 0.2713 | 2705 | T | SMT
51 | 1 | 13.56MHz | U5 | XQFN-8_L1.6-W1.6-P0.50-TL | 13.56MHz | NT3H2211W0FHKH | NXP(恩智浦) | C2905792 | LCSC | 0.1341 | 2 | T | SMT
52 | 1 | 74AHCT1G125GV | U6 | SOT-23-5_L3.0-W1.7-P0.95-LS2.8-BL |  | 74AHCT1G125GV | MDD(辰达半导体) | C52140417 | LCSC | 0.0118 | 2841 | T | SMT
53 | 1 | 2.4GHz | U8 | WIRELM-SMD_ESP32-S3-WROOM-1 | 2.4GHz | ESP32-S3-WROOM-1-N16R8 | ESPRESSIF(乐鑫) | C2913202 | LCSC | 0.8002 | 54294 | B | SMT
54 | 1 | SX1308 | U9 | SOT-23-6_L2.9-W1.6-P0.95-LS2.8-BL |  | SX1308 | SX(硕芯科技) | C78162 | LCSC | 0.0159 | 17946 | B | SMT
55 | 1 | PAM8302AASCR | U10 | MSOP-8_L3.0-W3.0-P0.65-LS5.0-BL |  | PAM8302AASCR | DIODES(美台) | C113367 | LCSC | 0.0321 | 6851 | B | SMT
56 | 1 | AP3032KTR-G1 | U11 | SOT-23-6_L2.9-W1.6-P0.95-LS2.8-BR | - | AP3032KTR-G1 | DIODES(美台) | C264086 | LCSC | 0.0405 | 11909 | B | SMT
57 | 1 | MAX17048G+T10 | U12 | TDFN-8_L2.0-W2.0-P0.50-BL-EP1.2 |  | MAX17048G+T10 | ADI(亚德诺)/MAXIM(美信) | C2682616 | LCSC | 0.305 | 8340 | B | SMT
58 | 1 | LIS3DHTR | U13 | LGA-16_L3.0-W3.0-P0.50-TL |  | LIS3DHTR | ST(意法半导体) | C15134 | LCSC | 0.2379 | 5428 | T | SMT
59 | 1 | AP2120N-1.3TRG1 | U14 | SOT-23-3_L2.9-W1.5-P2.0-LS2.5-BR |  | AP2120N-1.3TRG1 | DIODES(美台) | C6861079 | LCSC | 0.0186 | 470 | B | SMT
60 | 1 | E6C0603IRAC1UDA(940nm) | U16 | LED-SMD_L1.6-W0.8-R-RD |  | E6C0603IRAC1UDA(940nm) | ekinglux(亿晶源) | C396644 | LCSC | 0.0076 | 2963 | T | SMT
61 | 1 | AP2125K-2.8TRG1 | U17 | SOT-23-5_L3.0-W1.7-P0.95-LS2.8-BR |  | AP2125K-2.8TRG1 | DIODES(美台) | C176952 | LCSC | 0.011 | 1358 | B | SMT
62 | 1 | HEAD2 | U18 | HDR-TH_2P-P2.54-V-M |  | HEAD2 |  | C9900010030 | LCSC | 0.0002 | 0 | T | DIP
63 | 1 | TPS63001DRCR | U19 | VSON-10_L3.0-W3.0-P0.50-TL-EP_TPS62410DRCR |  | TPS63001DRCR | TI(德州仪器) | C28060 | LCSC | 0.262 | 1031 | B | SMT
64 | 1 | USB4105-GF-A-060 | USB1 | USB-C-SMD_GT-USB-7010E-1 |  | USB4105-GF-A-060 | GCT | C3025063 | LCSC | 0.1591 | 836 | B | DIP

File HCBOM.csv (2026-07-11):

Item | Count | Price of All Units | Price With Shipping/Tax | Link
PCB | 5 | $27.70 | N/A | (JLCPCB)
PCBA | 2 | $84.99 | N/A | (JLCPCB)
PCB + PCBA + Ship/Tax | 1 | $226.91 | N/A | (JLCPCB)
Displays w Shipping | 2 | 24.72 | 47.19 | https://www.digikey.com/en/products/detail/winstar-display/WF28JTYAJDNN0/20533259
Camera Modules | 2 | $19.90 | $0 | https://www.amazon.com/JESSINIE-Monitoring-Identification-Connector-Support/dp/B0B5XGMTSZ
Thermal Printer | 1 | $25.99 | $0 | https://www.amazon.com/Printing-Printpod-Impresora-Flashcards-Compatible/dp/B0DGXDR3HH
Batteries | 2 | $18.18 | $0 | https://www.amazon.com/Qimoo-Battery-Rechargeable-Connector-Electronic/dp/B0CNLPK1F8?s=electronics
Total | 1 | $402.48 | N/A | N/A

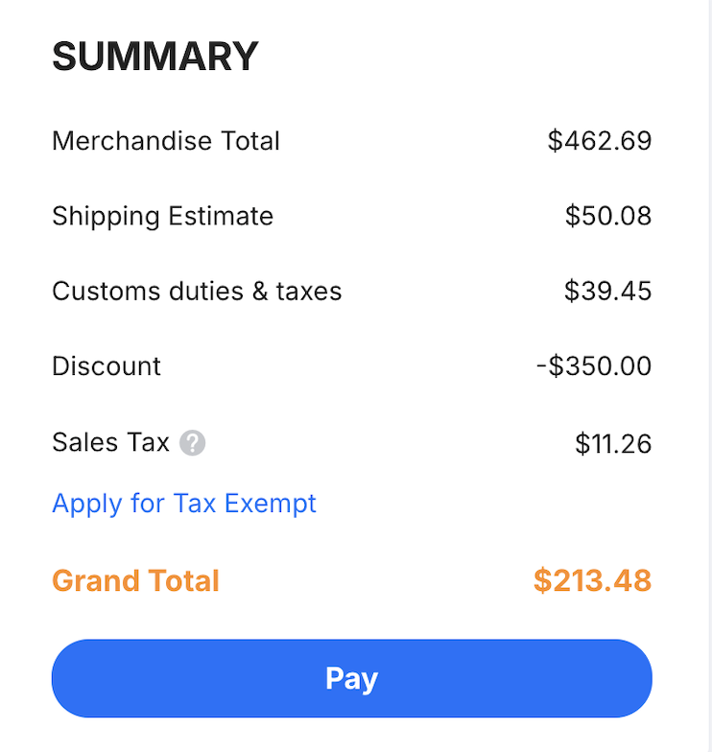
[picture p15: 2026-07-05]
Gerber_Order/Receipt.png

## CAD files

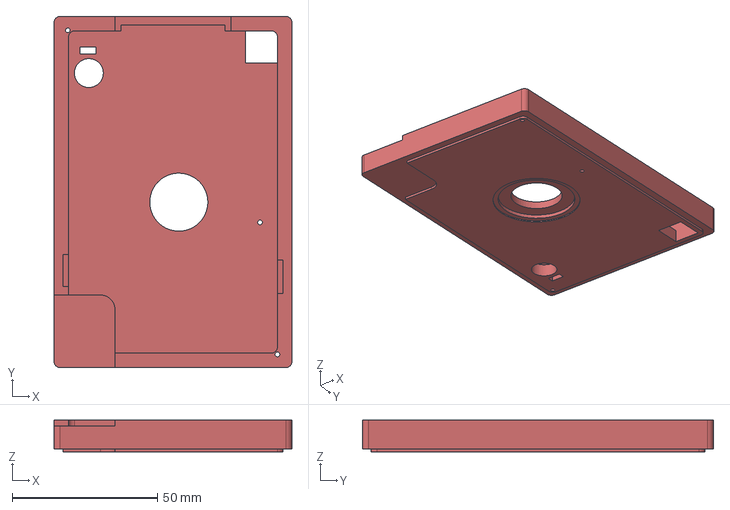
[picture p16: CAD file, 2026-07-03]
CAD/BottomCASE.step
82.0 x 121.0 x 11.0 mm

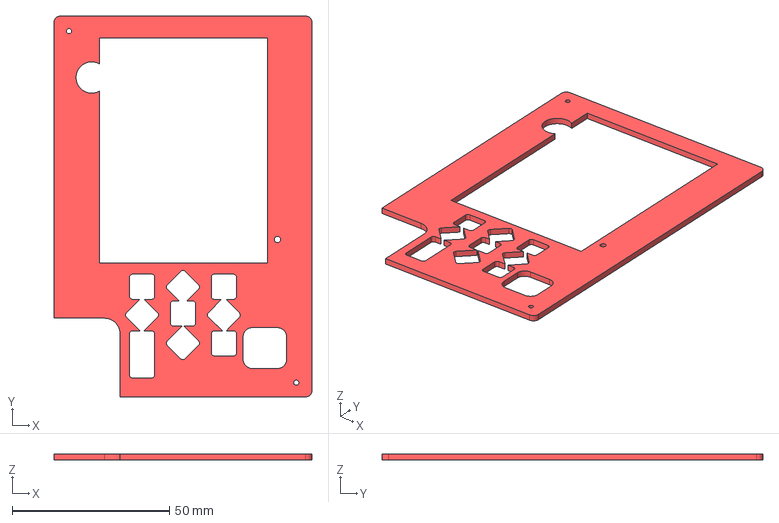
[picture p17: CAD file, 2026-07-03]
CAD/TopLID.step
82.0 x 121.0 x 2.00 mm

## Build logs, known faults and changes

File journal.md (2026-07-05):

## Development Log

### June ≤15th — Power System & Charging

**Goal:** Establish reliable power distribution and charging infrastructure

I identified all required components and sourced them from JLCPCB for easy access and datasheet reference. My primary focus was setting up a charging system for the rechargeable LiPo battery. I designed the complete charging circuit including the charging IC, ESD protection, and USB connector.

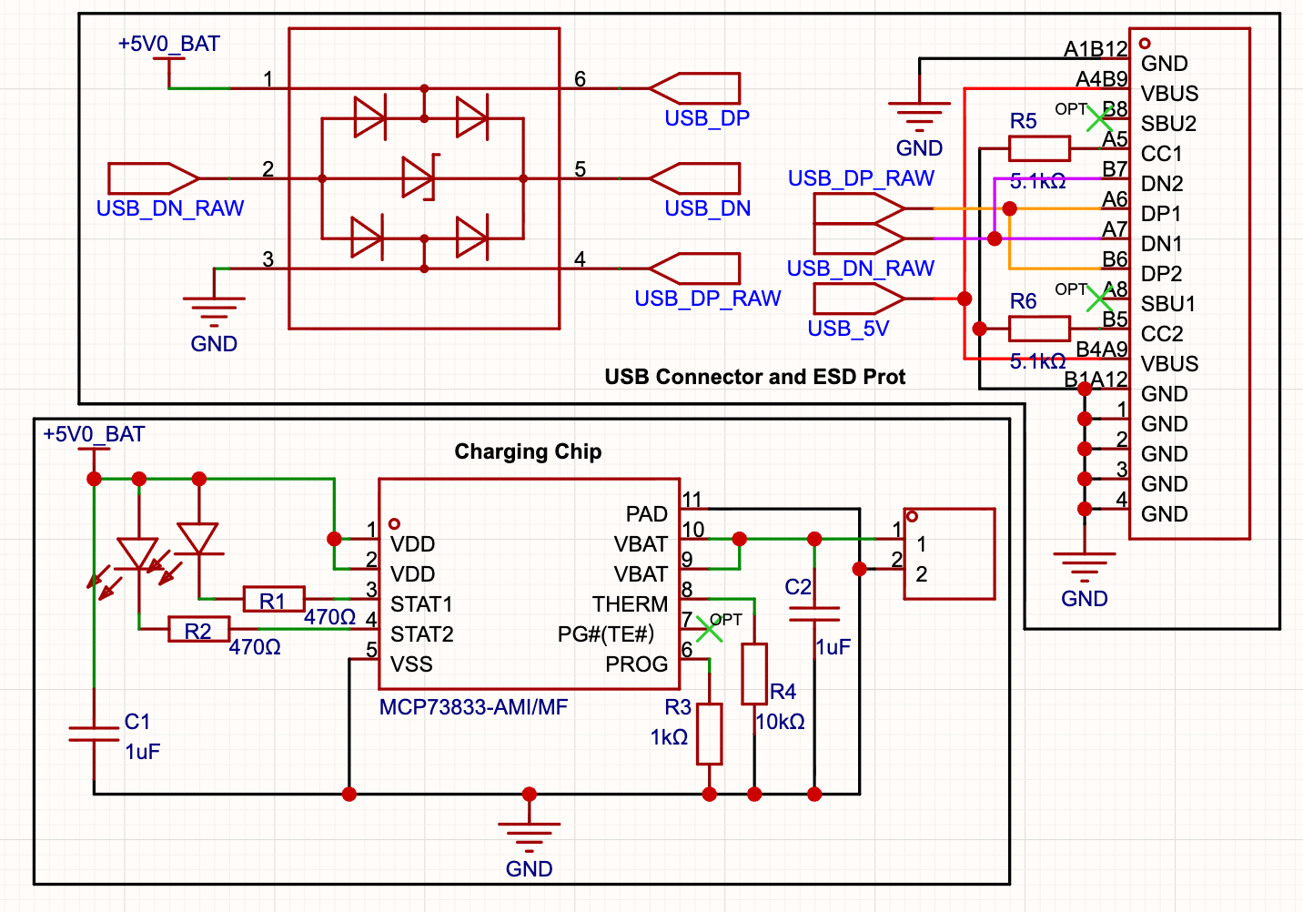
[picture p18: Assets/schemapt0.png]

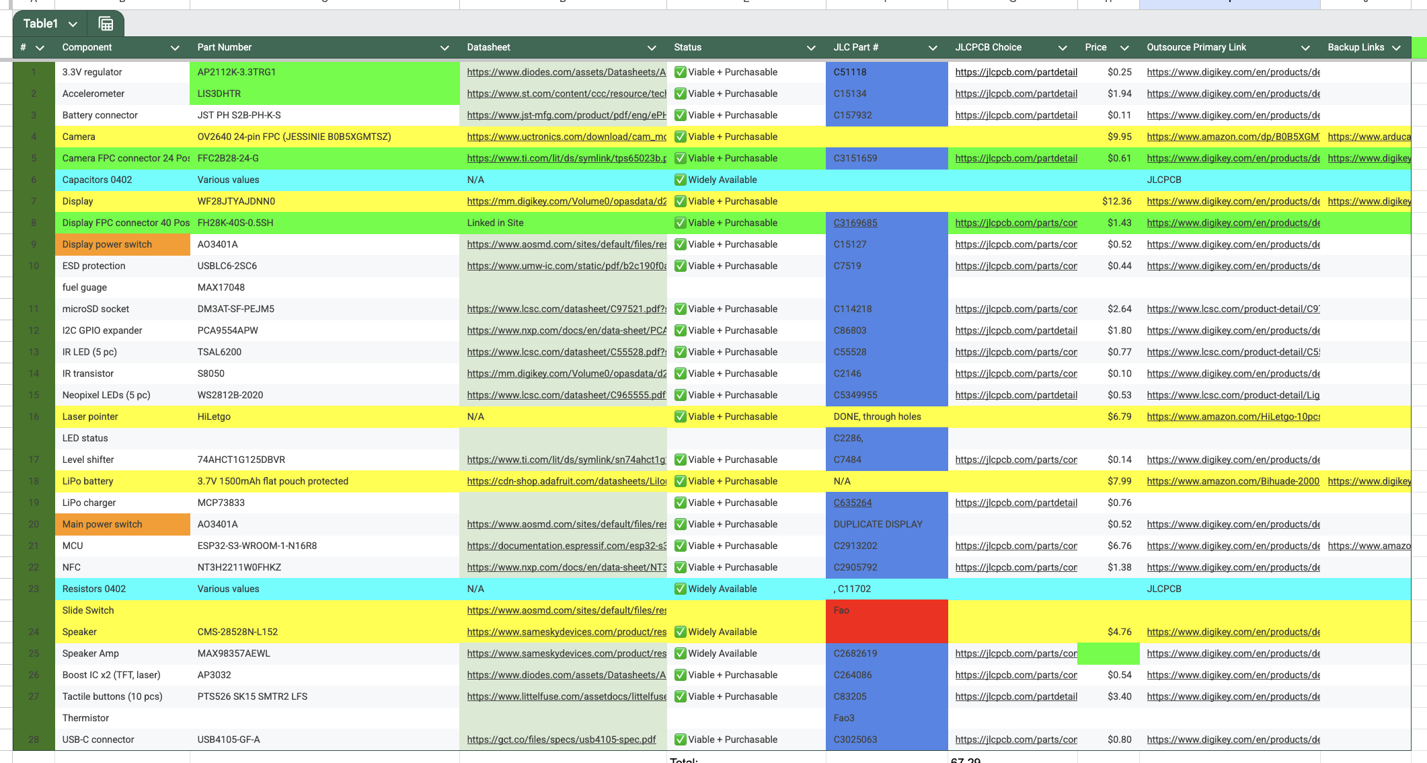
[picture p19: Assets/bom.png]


**Time Spent:** 3 hrs

---

### June 17th — Voltage Regulation & ESP32 Pinout

**Goal:** Complete power delivery and microcontroller initialization

I finalized the battery voltage regulation section and began mapping the essential ESP32 pins (power, reset, and boot). This established the foundation for the rest of the digital systems on the badge.

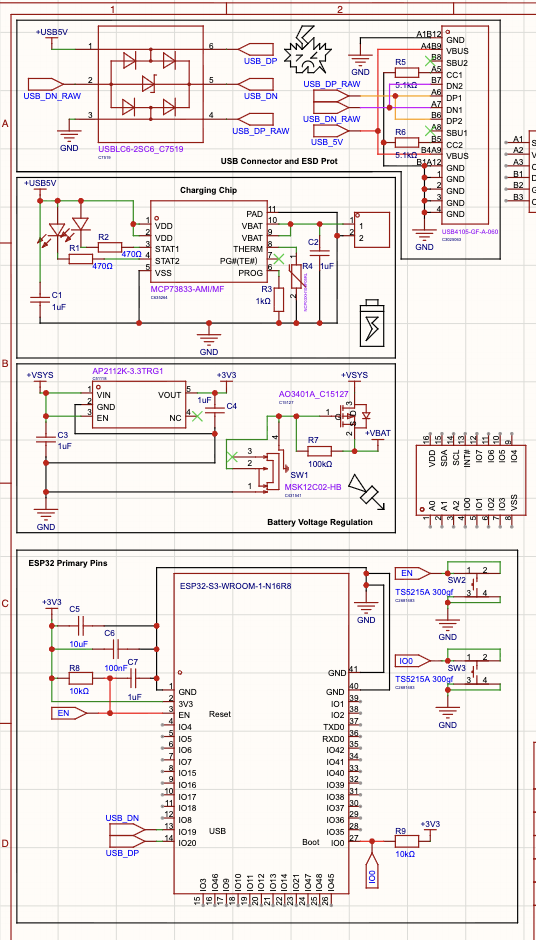
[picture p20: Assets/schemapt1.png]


**Time Spent:** 2 hrs

---

### June 18th-19th — Sensors & I/O Expansion

**Goal:** Integrate motion sensing and expand GPIO capabilities

With the power system complete, I moved on to the peripheral modules. I wired up the accelerometer (for camera/game mode detection) and configured the primary I/O expander to handle additional I/O requirements.

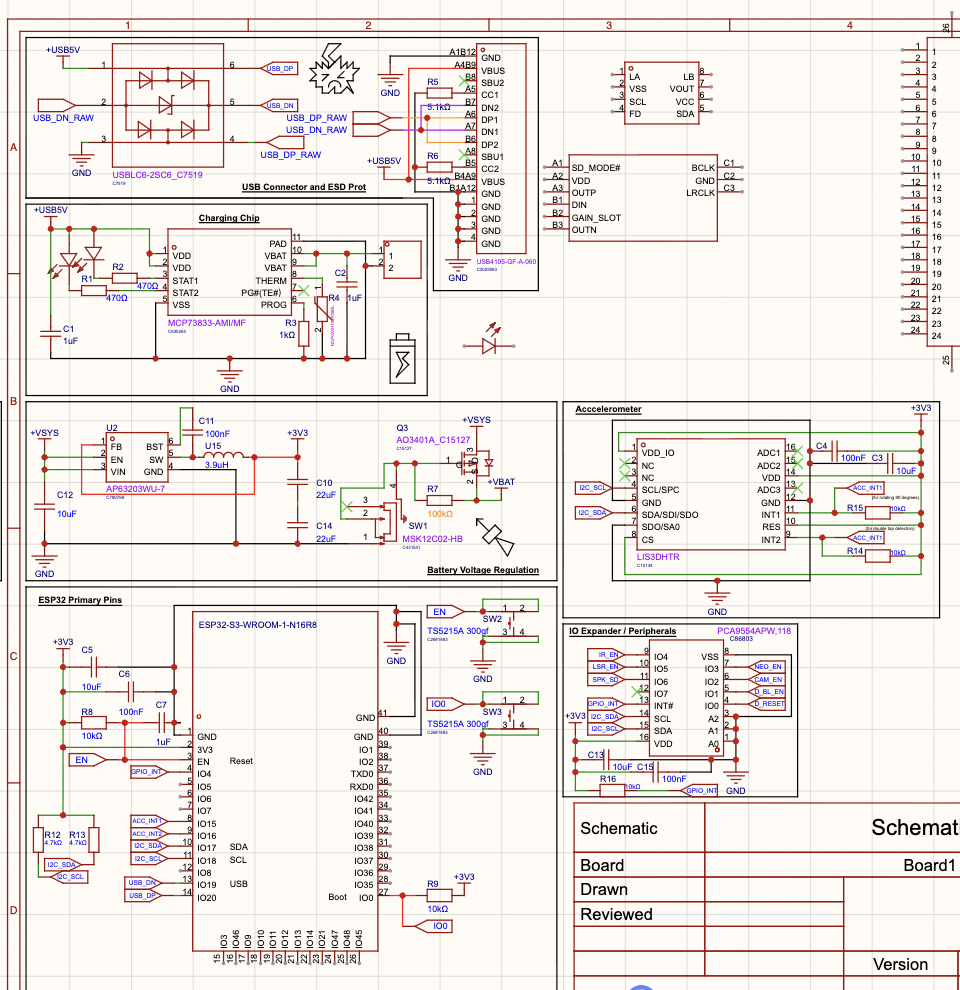
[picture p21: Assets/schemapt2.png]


**Time Spent:** 2.2 hrs

---

### June 22nd-24th

**Goal:** IR Blaster and more ESP32 Progress

I figured out how to wire the IR Blaster correctly and I recalculated how to use my ESP32 pins so they can cover all the components (ended up needing every last one!) Then on the 23rd and 24th I successfully wired my display connector, camera connector, and created a key matrix + the nfc. The entirety of my schematic was essentially complete :D

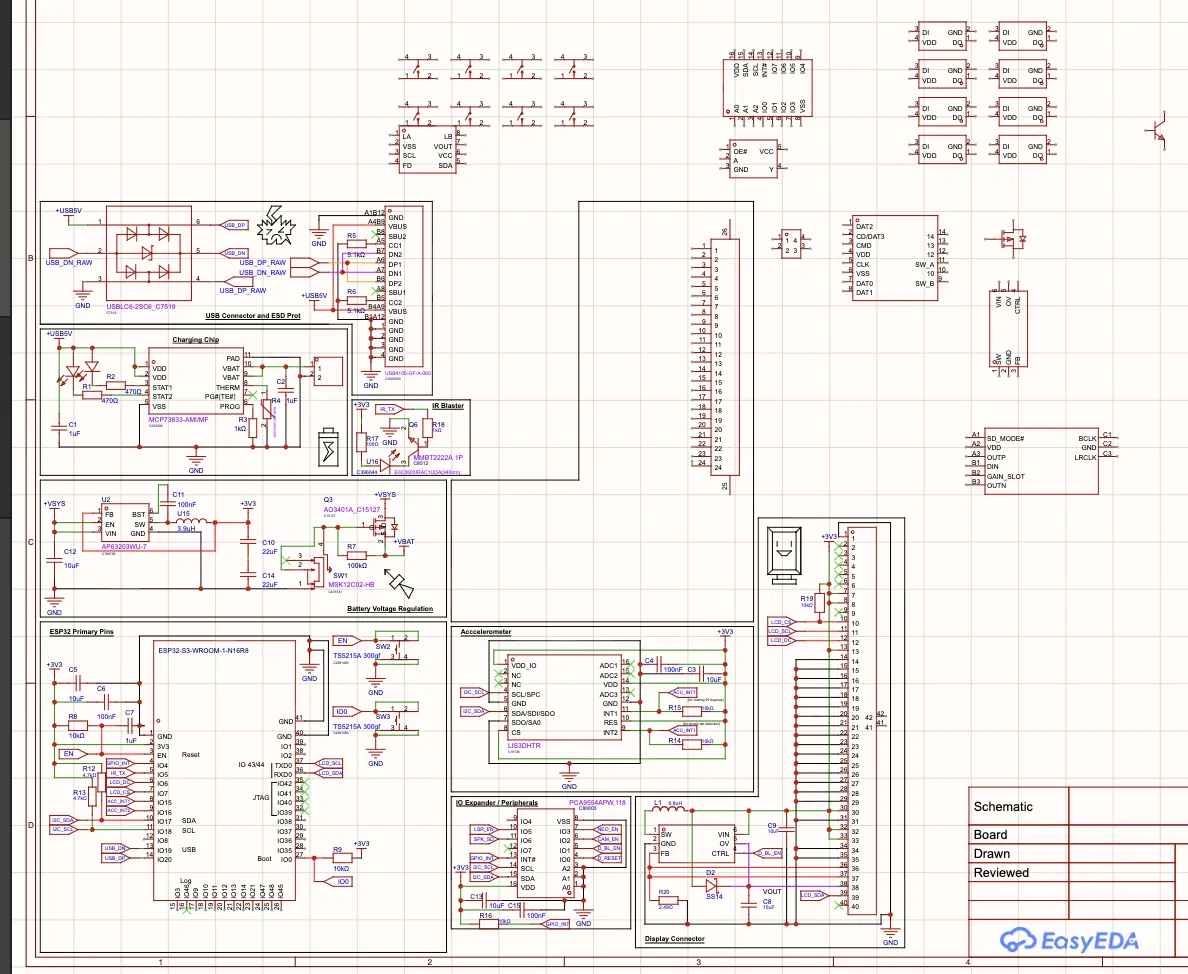
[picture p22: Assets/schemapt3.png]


**Time Spent:** 2.2 hrs

---

### June 25th

**Goal:** Finish schematic and start PCB

I finished my schematic! I added the buzzer, some additional necessary power rails, and started placing components on the PCB editor :D. I've decided to keep my NFC, display, and keys on the front, and the esp32 and power system related components on the back.
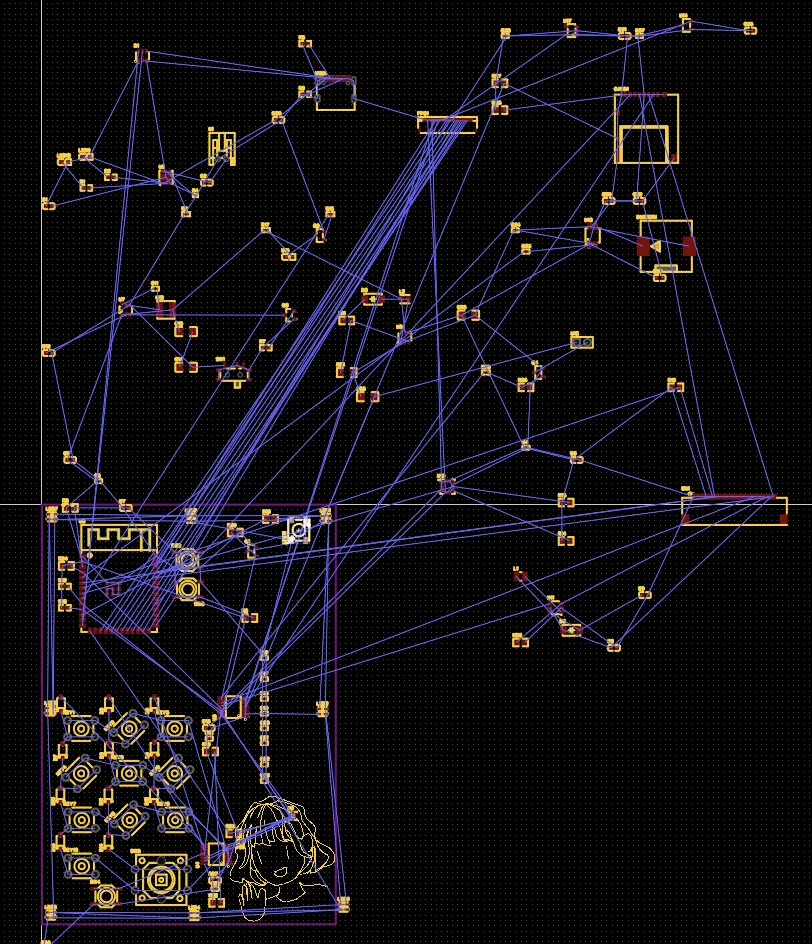
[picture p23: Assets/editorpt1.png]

CAD

Time Spent: 9 hrs

---

### June 27th-28th

**Goal:** Continue PCB

Today I did a lot more work on placing the components in the correct locations so there's no overlap and started mapping silkscreen too. 

Time Spent: 3.75 hrs

---

### June 29th

**Goal:** Route PCB

I wired almost the entire PCB and created two extra layers for my GND and 3v3 vias to tie to. 

Time Spent: 3.67 hrs

---

### July 2nd

**Goal:** Reduce PCB shipping time/cost and strengthen power rails.

I added more copper fill regions to my second layer for +1v3 and +2v8, increased the trace width of my +5v rail, double checked my DRC and created an optional CAD case for my badge. Then I submitted it to EasyEDA Spark in order to get some funds covered and try accelerate shipping so it can arrive in time.

Time Spent: 10 hrs

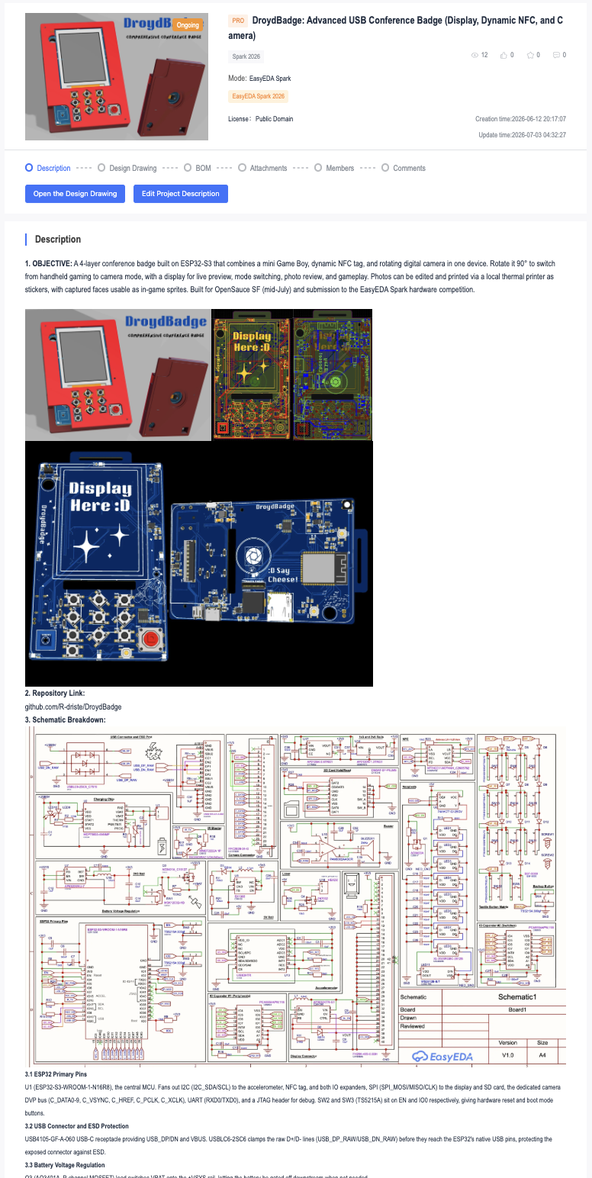
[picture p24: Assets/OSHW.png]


### July 3rd

I ordered my badge! :D Woohoo

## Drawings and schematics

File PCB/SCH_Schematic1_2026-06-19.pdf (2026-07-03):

# SDRAM

# micro-sd card

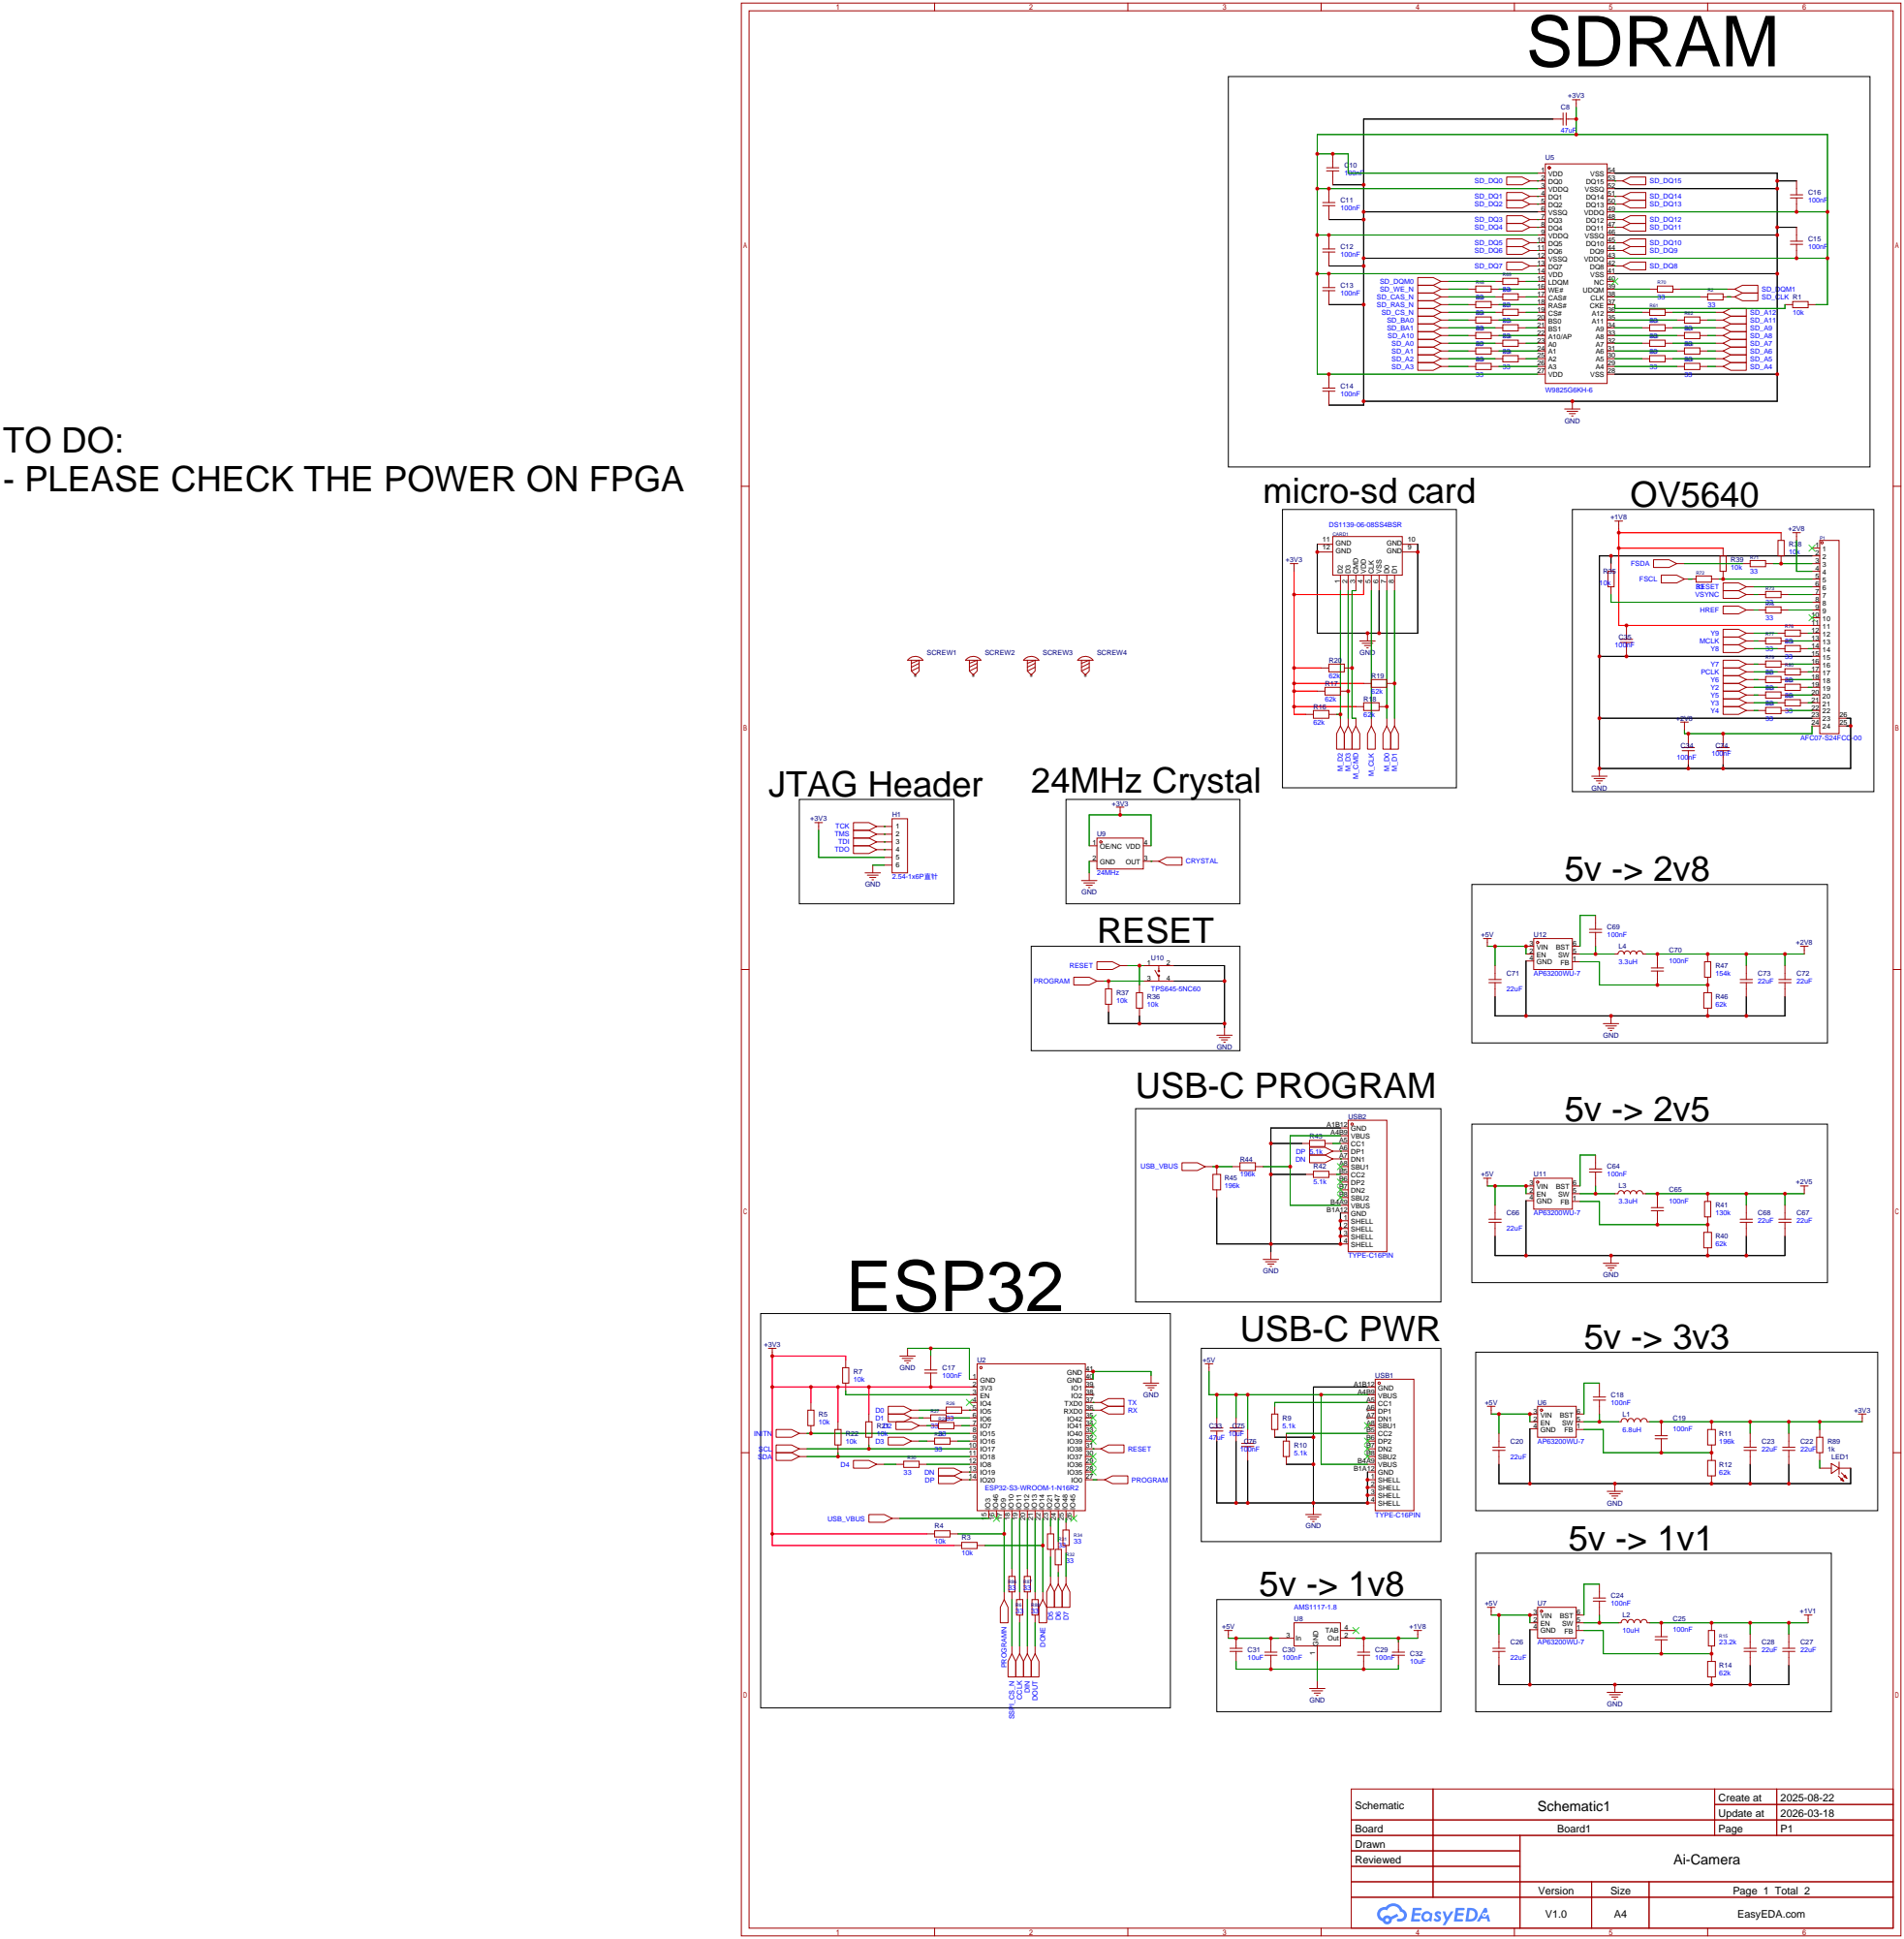
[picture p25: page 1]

Schematic | Schematic1 | Create at | 2025-08-22

Update at | 2026-03-18

Board | Board1 | Page | P1
Drawn | | Ai-Camera
Reviewed

Version | Size | Page 1 Total 2
V1.0 | A4 | EasyEDA.com

PR8A D16 | PL11D E1 PL8B E2 PL5C E3 PT9A E4 PT13A E5 PT20A E6 PT24A E7 PT33A E8 PT40B E9 PT47B E10 PT51B E11 PT58B E12 PT62B E13 PR5C E14 PR8B E15 PR11D E16 PL14A F1 PL11C F2 PL5D F3 PL8C F4 PL8D F5 VCCIO0 F6 VCCIO0 F7 GND F8 GND F9 VCCIO1 F10 VCCIO1 F11 PR8D F12 PR8C F13 PR5D F14 PR11C F15 PR14A F16 PL20A G1 PL14B G2 PL14C G3 PL11B G4 PL11A G5 VCC G6 VCC G7 GND G8 VCC G9 GND G10 VCCAUX G11 PR11A G12 PR11B G13 PR14C G14 PR14B G15 PR20A G16 GND H1 PL20B H2 PL14D H3 PL17B H4 PL17A H5 VCCIO7 H6 VCCIO7 H7 GND H8 GND H9 GND H10 VCCIO2 H11 PR17A H12 PR17B H13 PR14D H14 PR20B H15 GND H16
PR26C M16 | PL32A N1 GND N2 PL35D N3 PL38A N4 PL44D N5 PL47B N6 PB9A N7 PB15A N8 CCLK N9 CFG_0 N10 PR47B N11 PR44D N12 PR38A N13 PR35D N14 GND N15 PR32A N16 PL35A P1 PL32B P2 PL38B P3 PL41A P4 PL47D P5 PL47C P6 PB6B P7 PB13B P8 DONE P9 CFG_1 P10 PR47C P11 PR47D P12 PR41A P13 PR38B P14 PR32B P15 PR35A P16 PL35B R1 PL38C R2 PL41B R3 PL41C R4 PL44A R5 PB4B R6 PB6A R7 PB13A R8 PROGRAMN R9 CFG_2 R10 TDI R11 PR44A R12 PR41C R13 PR41B R14 PR38C R15 PR35B R16 GND T1 PL38D T2 PL41D T3 PL44B T4 GND T5 PB4A T6 PB11A T7 PB11B T8 INITN T9 TCK T10 TMS T11 GND T12 PR44B T13 PR41D T14 PR38D T15 GND T16

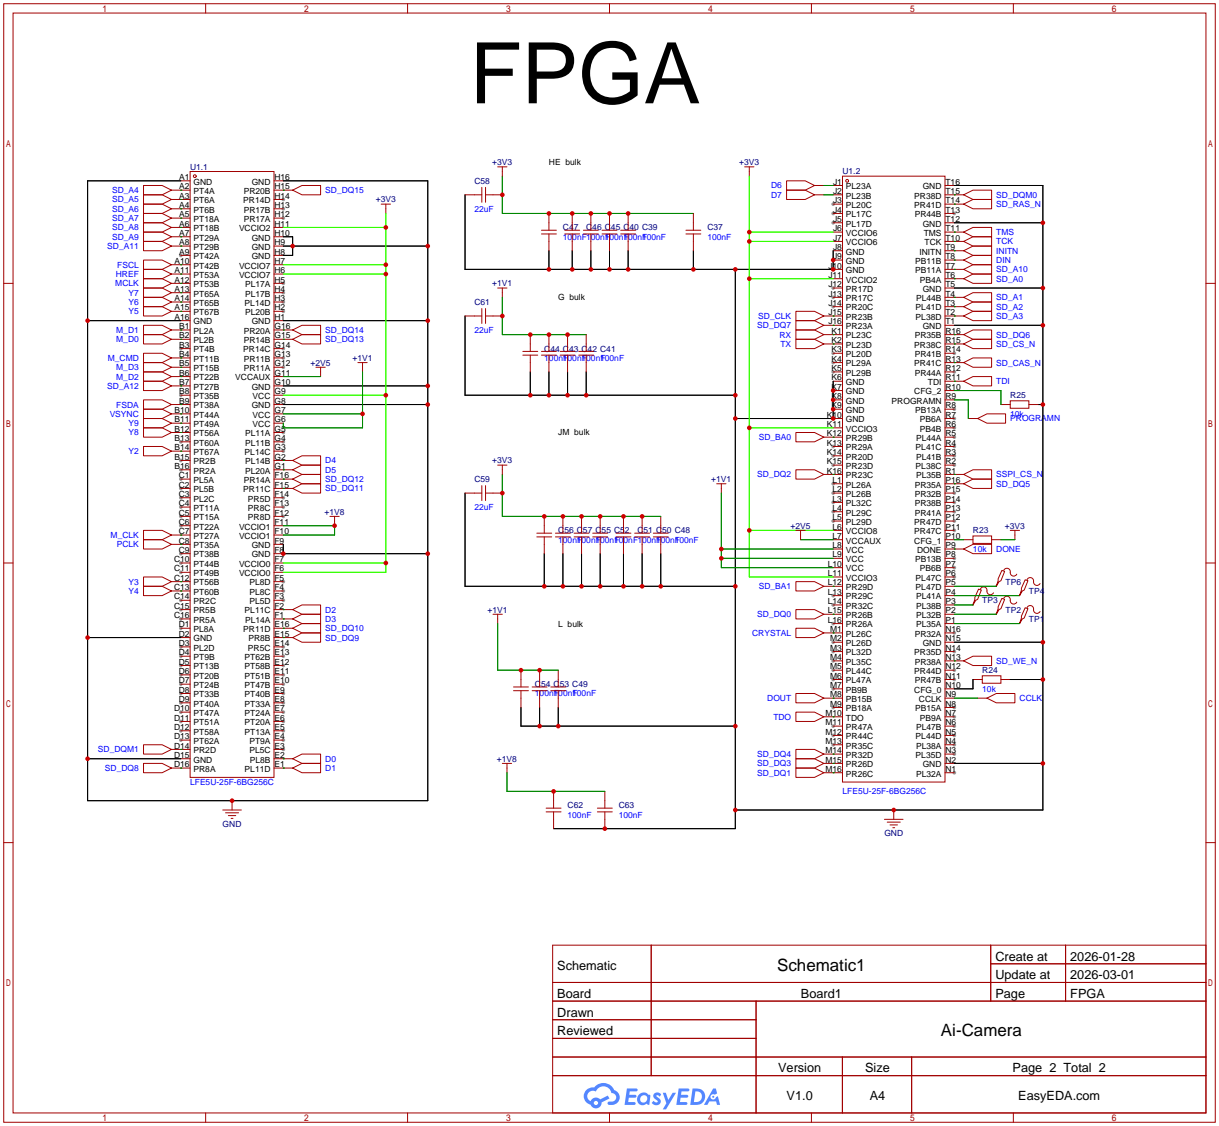
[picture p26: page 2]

Schematic | Schematic1 | Create at | 2026-01-28

Update at | 2026-03-01

Board | Board1 | Page | FPGA
Drawn | | Ai-Camera
Reviewed

Version | Size | Page 2 Total 2
V1.0 | A4 | EasyEDA.com

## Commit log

2026-07-02 cad file concept
2026-07-03 dristi roy files push
    [BOM_Board1_Schematic1_2026-07-02.xlsx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]
2026-07-11 :D added cost desc
    [HCBOM.csv]
2026-09-30 Update README with project status and acknowledgments
    Added work in progress note and PCB troubleshooting status.
